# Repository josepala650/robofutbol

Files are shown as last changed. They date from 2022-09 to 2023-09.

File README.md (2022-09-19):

# robofutbol
Robot para competencia robotfutbol
En este repositorio se encuentra el manual para ensamblar el mismo asi como las piezas que se necesitan .
Tambien puede verse el siguiente video:
https://www.youtube.com/watch?v=j2guSepUVq8&t=1s 
Captura de pantalla de 2022-04-13 15-39-39

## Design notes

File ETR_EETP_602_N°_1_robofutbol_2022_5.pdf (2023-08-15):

# Manual de robotfutbol con arduino

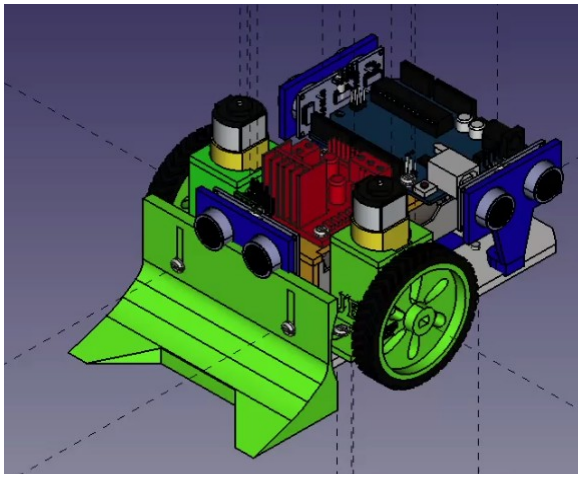
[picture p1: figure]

# Autor: Profesor Palacios José Emanuel

# Año: 2022 Institución: Escuela de Educación Técnico Profesional Nº 602 "Gral San Martín" www.eetp602.edu.ar

# Manual de Robot_Futbol con Arduino

# Contenido

Profesor Técnico Palacios José Emanuel | Página 2

# Manual de Robot_Futbol con Arduino

Introducción: Robotfutbol.

En este manual desarrollaremos un robotfutbol funcional básico, que se espera sufra modificaciones por quien lee este manual. Los robotsfutbol son robots que tienen como objetivo introducir una pelota en el arco del reival, para ellos son operados por radiocontrol (bluethooth, rf,etc). En el siguiente enlace se ve una descripción del robotfutbol.

# DIY Robot Futbolista - Campeonato Local de Robots [ARDUINO]

# https://youtu.be/g5vMoPJQiVI

Materiales.

- 1x Arduino uno
- 1x Chasis que cumpla con las normas de la categoría (se proporcionaran planos de ejemplo).
- 2x motoreductor arduino
- Rueda para motoreductor arduino ( se proporciona plano para su diseño 3d).
- shiel doble puente h l298n.
- Porta baterías 18650 x2.
- Baterías recargables tipo 18650 3.7v 5000 Mah
- Plug de alimentación DC 2.1mm
- 30 tornillos cabeza tanque de 1/8 de 10mm con tuerca.
- 2 tornillos cabeza tanque de 1/8 de 30mm con tuerca (para la pala).
- 2 tornillo m2 X 15mm(diametro2mm) para sujetar ruedas.
- 20 conector dupont macho hembra 10cm
- 20 conector dupont macho macho10cm
- Cable 1mm rojo y negro, 50cm.
- Tecla on/0ff.
- Modulo bluetooth HC06
- 4 Diodo rectificador 1n4007
- Cinta aisladora o termocontraible (de 3 a 1mm).
- Estaño
- Piezas del diseño de chasis (archivos stl para descargar https://youtu.be/j2guSepUVq8 )

# Manual de Robot_Futbol con Arduino

# Interruptor on/off y alimentación

Es conveniente agregar un interruptor para la alimentación del circuito, en serie a un diodo rectificador 1N4007 (para proteger el circuito en caso de conectar las baterías con la polaridad incorrecta), de acuerdo al consumo es la cantidad de diodos 1N4007 que conectaremos ya que cada diodo soporta 1A, en este caso conectaremos 2 diodos en paralelo para que soporten 2A, de necesitar que soporte mas amperaje incrementar la cantidad de diodos o colocar uno que soporte dicho amperaje.

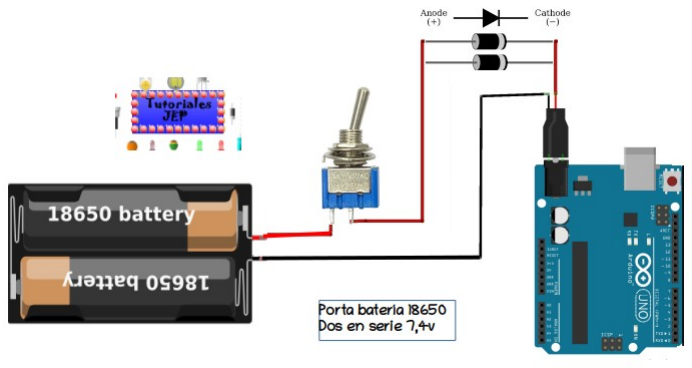
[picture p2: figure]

# Manual de Robot_Futbol con Arduino

# Control por Bluetooth

Este tutorial tiene el objetivo principal de dar los conocimientos necesarios para poder añadir a nuestro

Arduino la función de poder comunicarse sin cables con otros dispositivos mediante módulos Bluetooth y

poder empezar a incorporarlos en nuestro robot.

Es necesario saber que existen diferentes modelos de módulos Bluetooth entre los más populares se encuentran HC-06 y el HC05, y entre ellos diferentes modelos.

Un módulo Bluetooth HC-06 se comporta como esclavo, esperando peticiones de conexión, Si algún dispositivo se conecta, el HC-06 transmite a este todos los datos que recibe del Arduino y viceversa.

## Entonces, ¿cuáles son sus diferencias entre el modulo Bluetooth HC-06

# y el HC-05?

El módulo HC-06 es prácticamente idéntico a simple vista con los demás módulos que existen en el mercado.

Una simple diferencia es que el módulo HC-06 funciona como Slave y el HC-05 como Master y Slave (lo que podría confundir a algunos).

Físicamente se diferencian por el número de pines. En el HC-06 tiene un conector de 4 pines mientras que el HC-05 trae uno de 6 pines.

HC-06 | HC-05

Para este tutorial trabajaremos un módulo HC06 pero también es válido para un módulo HC-05 en modo Esclavo, que es su configuración que viene por defecto.

# EL HC-06 tiene 4 pines:

- Vcc, Voltaje positivo de alimentación, aquí hay tener cuidado porque hay módulos que solo soportan voltajes de 3.3V, pero en su mayoría ya vienen acondicionados para q trabajen en el rango de 3.3V a 6V

# pero es bueno revisar los dato técnicos de nuestro modulo antes de hacer las conexiones

- GND, Voltaje negativo de alimentación, se tienen que conectar al GND del Arduino o al GND de la placa que se esté usando.
- TX, Pin de Transmisión de datos, por este pin el HC-06 transmite los datos que le llegan desde la PC o

# Móvil mediante bluetooth, este pin debe ir conectado al pin RX del Arduino

# Manual de Robot_Futbol con Arduino

-RX, pin de Recepción, a través de este pin el HC-06 recibirá los datos del Arduino los cuales se

# transmitirán por Bluetooth, este pin va conectado al Pin TX del Arduino

Explicado esto, para comenzar a hacer pruebas y comprobar que nuestro HC-06 nos funciona correctamente, usando cables Dupont macho-hembra procedemos a realizar las siguientes conexiones entre nuestro modulo Bluetooth y nuestro Arduino UNO R3(se pueden realizar las mismas conexiones con el Arduino Mega, Arduino Nano, etc. e iría perfectamente).

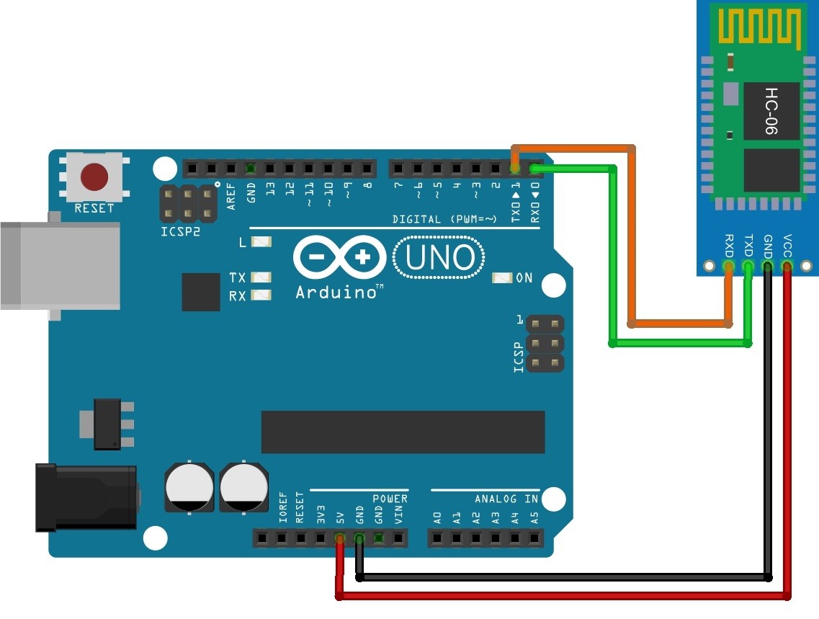
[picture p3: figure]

Para cargar el programa al Arduino, desconectaremos los pines RX0 y TX0 del Arduino, pues internamente el Arduino trabaja con los mismos pines para cargar el programa y si están conectados al módulo Bluetooth, no nos dejara cargar (para evitar este inconveniente se puede usar el software serial y usar otros pines).

# Manual de Robot_Futbol con Arduino

Ahora en el IDE de Arduino copiamos el siguiente código y luego lo cargamos a nuestro Arduino.

/**********************************************************************/
/* Autor: Palacios José Emanuel docente de la EETPN°602 | */
/* Programa:Prueba bluetooth | */
/* Año:2022 | */
/**********************************************************************/

# void setup()

{
Serial.begin(9600);

pinMode(12, OUTPUT); // configuro el pin 13 como salida
}

# void loop()

{

# if (Serial.available())

{
char dato=Serial.read();

# if (dato=='a')

{

# digitalWrite(13,HIGH); //envió 5V al pin13 donde esta conectado el led

}

# if (dato=='b')

{

# digitalWrite(13,LOW); //envió 0V al pin13 donde esta conectado el led

}
}
}
Después | de | terminar | de | cargar, | nuevamente | volvemos | a | conectar | los | pines | RX | y TX.

El programa que hemos cargado al Arduino básicamente de acuerdo al dato que reciba del Bluetooth ( a o b) prendera o apagara el led conectado al pin13.

# En el siguiente videotutorial se muestra como hacer la app para control por bluetooth

Crear Aplicación para Carro a Control Remoto (Tutorial):https://youtu.be/MiWLzbpfqr0

En el siguiente enlace encontrara una app de manejo por bluetooth que permite su configuración según se

necesite.

https://play.google.com/store/apps/details?id=nextprototypes.BTSerialController&hl=es_AR&gl=US

# Manual de Robot_Futbol con Arduino

# Control de Motores

Nos queda por probar el movimiento de los motores, estos funcionan con un voltaje de corriente directa, para controlar el giro y la velocidad se usará un driver de motores.

Primero soldaremos los cables a los motores.

Se deben soldar los cables de manera perpendicular al motor de modo que la longitud del motor sea lo más corta posible (ahora que se ha incluido el cable).

Una vez soldados los motores debemos conectarlos al driver.
Shiel doble puente h l298n.

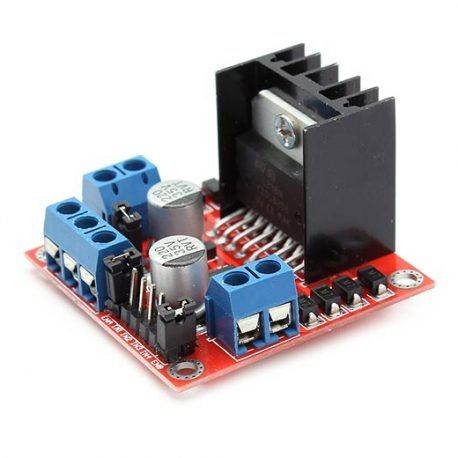
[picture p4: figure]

# Manual de Robot_Futbol con Arduino

Este módulo es el complemento ideal para proyectos de robótica y Router CNC. Permite controlar hasta 2

motores de corriente continua o un motor paso a paso bipolar. También permite controlar un motor paso a

paso unipolar configurado como bipolar de forma muy sencilla y eficaz.

### Características

- Voltaje de alimentación, mínimo de 5 V. Posee dos entradas, una de 5V para controlar la parte lógica y otra para alimentar las salidas al motor, que pueden ser de 5V o más.
- La tarjeta tiene la opción de habilitar un regulador LM7805 integrado en ella para alimentar la parte lógica con lo que se puede alimentar la tarjeta con 12V por ejemplo.
- Corriente máxima 2 Amperios.

# - Posee 6 entradas de control (ver tabla de control)

- Admite entradas de señal PWM para el control de velocidad.
- Dimensiones: 43 mm x 23,9 mm x 43 mm.
- Salidas: para 2 motores de DC o para un motor bipolar paso a paso.

# Manual de Robot_Futbol con Arduino

# Funcionamiento del puente H

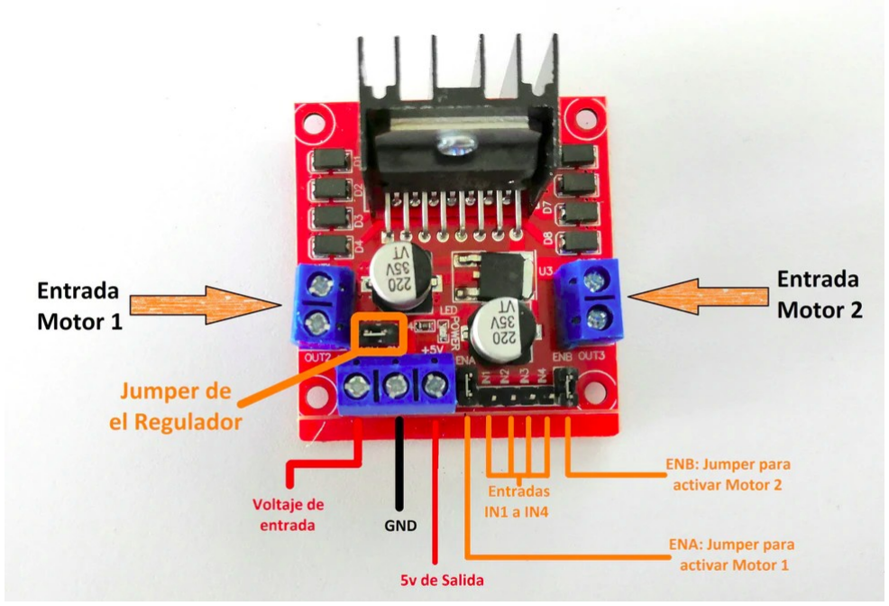
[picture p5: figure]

El voltaje de entrada puede ser desde 3v hasta 35v, aun lado de la entrada de voltaje contamos con el

GND

# La tercera es la salida lógica de 5v la cual se utiliza de la siguiente manera:

- Si el jumper se encuentra puesto se activará el regulador de tensión y tendremos una salida de 5V, que podremos usar para darle potencia a otro componente.
- Si quitamos el jumper desactivaremos el regulador, necesitaríamos alimentar el módulo, Tendríamos que ingresar 5v por la salida lógica para que el modulo funcione.
- ¡PRECAUCION! Si ingresamos 5v por la parte lógica con el jumper puesto podríamos causar daño a la tarjeta.
- El regulador solo nos funciona si ingresamos un voltaje desde 5v hasta 12v, Si queremos ingresar un voltaje mayor tendríamos que quitar el jumper y alimentar el modulo con 5v con una fuente externa.

Las salidas de los motores 1 y 2 nos dan energía para mover los motores. Hay que tomar en cuenta las polaridades de los motores para que queden girando hacia adelante. En caso de que un motor este girando al lado contrario solo es necesario invertir los cables.

Los dos pines IN1 e IN2 sirven para controlar el sentido de giro en el motor 1, y los dos pines IN3 e IN4 el sentido de giro del motor 2.

# Manual de Robot_Futbol con Arduino

# Funcionan de la siguiente manera:

Si IN1 le llegan 5v y al IN2 0v, el motor 1 gira en un sentido, y si IN1 le llegan 0v y a IN2 5v lo hace en el sentido contrario.

Sería lo mismo con los pines IN3 e IN4 para el motor 2.

Para controlar la velocidad a la que van a girar los motores tenemos que retirar los jumpers en ENA y ENB. Los tenemos que conectar a dos salidas PWM de nuestro Arduino con el cual enviaremos una señal con un valor entre 0 y 255 para que controle la velocidad de giro. Si no quitamos los jumpers, los motores estarán

# girando a la misma velocidad siempre( que es el caso que se explica en este tutorial)

La siguiente imagen muestra las conexiones a realizar, para los pines ENA y ENB se dejan con los jumpers pero si quieren controlar la velocidad podemos utilizar cualquier conexión PWM en el arduino quitando los jumpers.

Conexiones

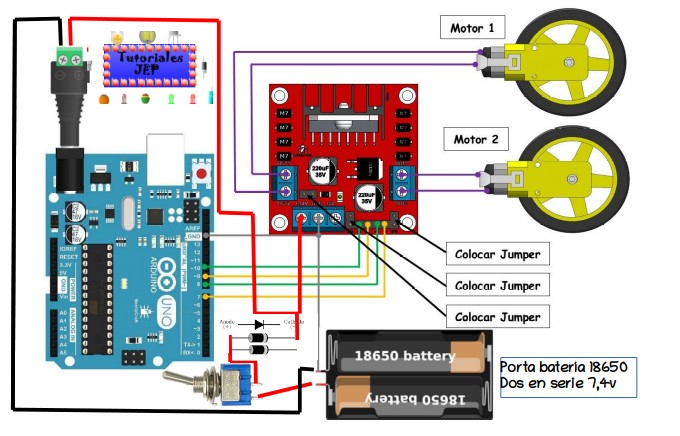
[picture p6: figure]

# Manual de Robot_Futbol con Arduino

# Programación para controlar el puente h

A continuación tenemos un código de ejemplo para controlar los motores:

/**********************************************************************/
/* Autor: Palacios José Emanuel docente de la EETPN°602 | */
/* Programa:Prueba motores | */
/* Año:2022 | */
/**********************************************************************/

// Conexiones puente h
//motor 1
int IN1=10; // enmascaro al pin 10 con el nombre de IN1 int IN2=9; // enmascaro al pin 9 con el nombre de IN2

//motor 2
int IN3=8; // enmascaro al pin 8 con el nombre de IN3
int IN4=7; // enmascaro al pin 7 con el nombre de IN4

// **************************** Inicialización *************************************
void setup() {
pinMode(IN1, OUTPUT); // configuro el pin donde conecte IN1 como salida pinMode(IN2, OUTPUT); // configuro el pin donde conecte IN2 como salida pinMode(IN3, OUTPUT); // configuro el pin donde conecte IN3 como salida pinMode(IN4, OUTPUT); // configuro el pin donde conecte IN4 como salida
}

//***************************** programa principal *******************************
void loop() {

//giro motor 1 sentido horario
digitalWrite(IN1,HIGH); //envió 5V al pin donde conecte IN1 digitalWrite(IN2,LOW); //envió 0V al pin donde conecte IN2 delay(1000); // Temporiza un segundo (1s = 1000ms)

//giro motor 1 sentido anti horario
digitalWrite(IN1,LOW); //envió 0V al pin donde conecte IN1 digitalWrite(IN2,HIGH); //envió 5V al pin donde conecte IN2 delay(1000); // Temporiza un segundo (1s = 1000ms)

//motor 1 DETENIDO
digitalWrite(IN1,LOW); //envió 0V al pin donde conecte IN1 digitalWrite(IN2,LOW); //envió 0V al pin donde conecte IN2 delay(1000); // Temporiza un segundo (1s = 1000ms)

//giro motor 2 sentido horario
digitalWrite(IN3,HIGH); //envió 5V al pin donde conecte IN3 digitalWrite(IN4,LOW); //envió 0V al pin donde conecte IN4 delay(1000); // Temporiza un segundo (1s = 1000ms)

//giro motor 2 sentido antihorario
digitalWrite(IN3,LOW); //envió 0V al pin donde conecte IN3 digitalWrite(IN4,HIGH); //envió 5V al pin donde conecte IN4 delay(1000); // Temporiza un segundo (1s = 1000ms)

//motor 2 DETENIDO
digitalWrite(IN3,LOW); //envió 0V al pin donde conecte IN3

# Manual de Robot_Futbol con Arduino

digitalWrite(IN4,LOW); //envío 0V al pin donde conecte IN4 delay(1000); // Temporiza un segundo (1s = 1000ms)
}

# Manual de Robot_Futbol con Arduino

## Lógica de movimiento

La estructura que hemos elegido para nuestro robot nos permitirá realizar movimientos hacia Adelante, hacia Atrás, giros a la Derecha, ala Izquierda y sobre sí mismo.
Movimiento hacia delante: Se hacen girar los dos motores en la misma dirección (sentido horario), esto provoca un movimiento recto hacia delante de la estructura.

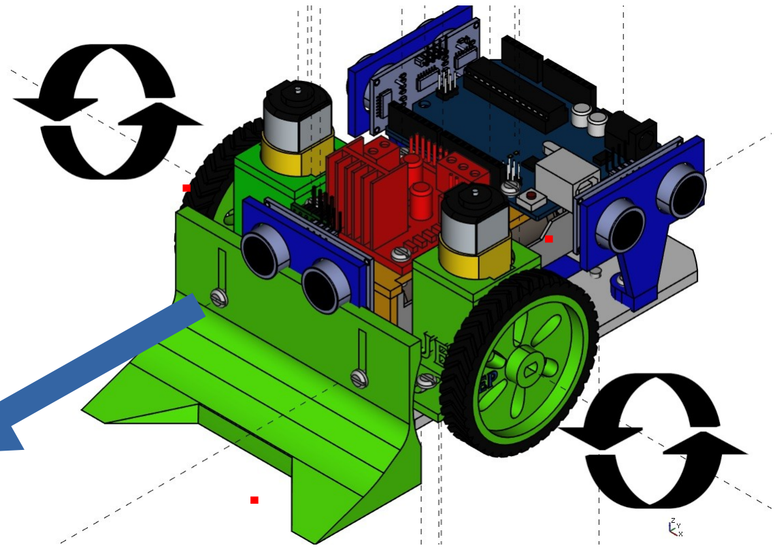
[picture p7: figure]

Movimiento hacia atrás: Se hacen girar los dos motores en la misma dirección (antihorario), esto provoca un movimiento recto hacia atrás de la estructura.

# Manual de Robot_Futbol con Arduino

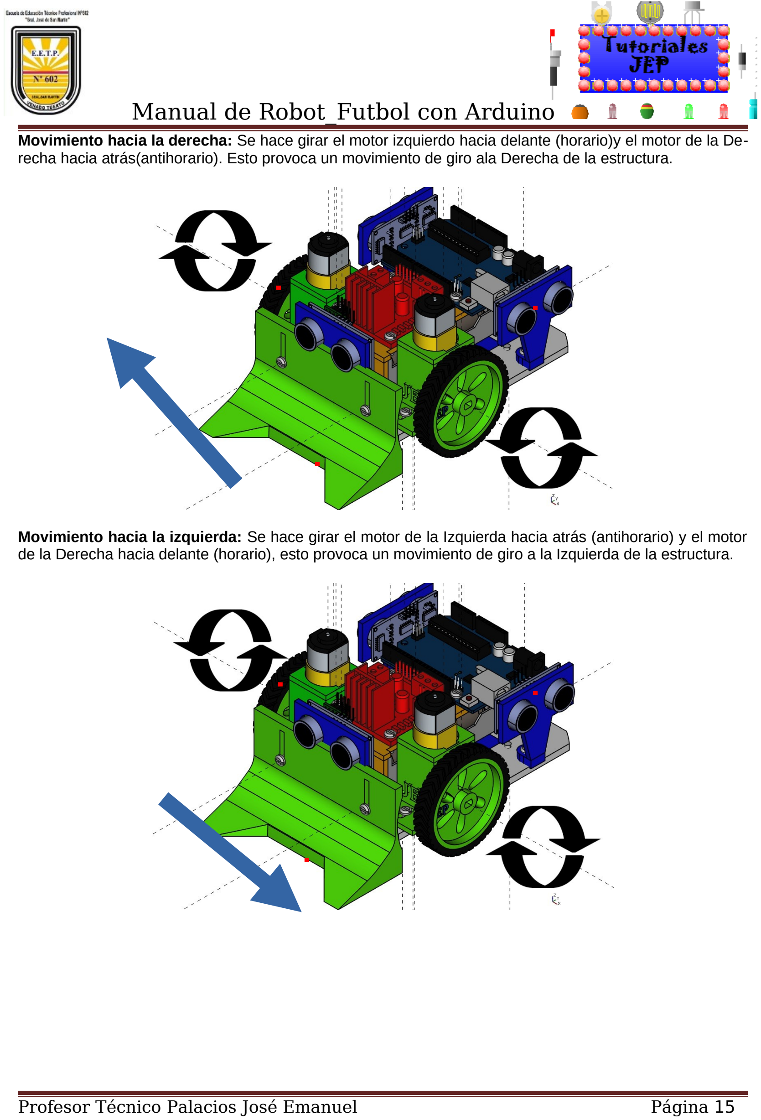
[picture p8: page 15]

Movimiento hacia la derecha: Se hace girar el motor izquierdo hacia delante (horario)y el motor de la Derecha hacia atrás(antihorario). Esto provoca un movimiento de giro ala Derecha de la estructura.

Movimiento hacia la izquierda: Se hace girar el motor de la Izquierda hacia atrás (antihorario) y el motor de la Derecha hacia delante (horario), esto provoca un movimiento de giro a la Izquierda de la estructura.

# Manual de Robot_Futbol con Arduino

# El código de Arduino quedaría de la siguiente manera:

/**********************************************************************/
/* Autor: Palacios José Emanuel docente de la EETPN°602 | */
/* Programa:movimiento de robot | */
/* Año:2022 | */
/**********************************************************************/
// Conexiones puente h
//motor 1_izquierdo
int IN1=10; // enmascaro al pin 10 con el nombre de IN1
int IN2=9; // enmascaro al pin 9 con el nombre de IN2

//motor 2_derecho
int IN3=8; // enmascaro al pin 8 con el nombre de IN3 int IN4=7; // enmascaro al pin 7 con el nombre de IN4

void setup()
{

pinMode(IN1, OUTPUT); // configuro el pin donde conecte IN1 como salida pinMode(IN2, OUTPUT); // configuro el pin donde conecte IN2 como salida pinMode(IN3, OUTPUT); // configuro el pin donde conecte IN3 como salida pinMode(IN4, OUTPUT); // configuro el pin donde conecte IN4 como salida
}

void loop()
{
// voy hacia adelante por un segundo

//giro motor 1 sentido anti horario
digitalWrite(IN1,LOW); //envió 0V al pin donde conecte IN1 digitalWrite(IN2,HIGH); //envió 5V al pin donde conecte IN2 //giro motor 2 sentido horario
digitalWrite(IN3,HIGH); //envió 5V al pin donde conecte IN3 digitalWrite(IN4,LOW); //envió 0V al pin donde conecte IN4 delay(1000);// demora de un segundo

//voy hacia atrás por un segundo

//giro motor 1 sentido horario
digitalWrite(IN1,HIGH); //envió 5V al pin donde conecte IN1 digitalWrite(IN2,LOW); //envió 0V al pin donde conecte IN2 //giro motor 2 sentido antihorario
digitalWrite(IN3,LOW); //envió 0V al pin donde conecte IN3 digitalWrite(IN4,HIGH); //envió 5V al pin donde conecte IN4 delay(1000);// demora de un segundo

//voy a la derecha con ambas ruedas por un segundo

//giro motor 1 sentido anti horario
digitalWrite(IN1,LOW); //envió 0V al pin donde conecte IN1 digitalWrite(IN2,HIGH); //envió 5V al pin donde conecte IN2 //giro motor 2 sentido antihorario
digitalWrite(IN3,LOW); //envió 0V al pin donde conecte IN3 digitalWrite(IN4,HIGH); //envió 5V al pin donde conecte IN4 delay(1000);// demora de un segundo

# Manual de Robot_Futbol con Arduino

// voy a la izquierda con ambas ruedas por un segundo

//giro motor 1 sentido horario
digitalWrite(IN1,HIGH); //envió 5V al pin donde conecte IN1 digitalWrite(IN2,LOW); //envió 0V al pin donde conecte IN2 //giro motor 2 sentido horario
digitalWrite(IN3,HIGH); //envió 5V al pin donde conecte IN3 digitalWrite(IN4,LOW); //envió 0V al pin donde conecte IN4 delay(1000);// demora de un segundo

// me detengo por un segundo

//motor 1 DETENIDO
digitalWrite(IN1,LOW); //envió 0V al pin donde conecte IN1 digitalWrite(IN2,LOW); //envió 0V al pin donde conecte IN2 //motor 2 DETENIDO
digitalWrite(IN3,LOW); //envió 0V al pin donde conecte IN3 digitalWrite(IN4,LOW); //envío 0V al pin donde conecte IN4 delay(1000);// demora de un segundo

// voy a la derecha con una rueda por un segundo

//giro motor 1 sentido anti horario
digitalWrite(IN1,LOW); //envió 0V al pin donde conecte IN1 digitalWrite(IN2,HIGH); //envió 5V al pin donde conecte IN2 delay(100);// demora de 10milisegundos
//motor 1 DETENIDO
digitalWrite(IN1,LOW); //envió 0V al pin donde conecte IN1 digitalWrite(IN2,LOW); //envió 0V al pin donde conecte IN2 delay(1000);// demora de un segundo

//voy a la izquierda con una rueda por un segundo

//giro motor 2 sentido horario
digitalWrite(IN3,HIGH); //envió 5V al pin donde conecte IN3 digitalWrite(IN4,LOW); //envió 0V al pin donde conecte IN4 delay(100);//demora de 10milisegundos
//motor 2 DETENIDO
digitalWrite(IN3,LOW); //envió 0V al pin donde conecte IN3 digitalWrite(IN4,LOW); //envío 0V al pin donde conecte IN4 delay(1000);// demora de un segundo

}

Con este programa comprobamos los movimientos del robot.

# Manual de Robot_Futbol con Arduino

Montaje de los componentes.

Cuando ya se han probado todos los componentes por separado lo siguiente es montar todo el circuito electrónico, sensores, motores y control en el chasis. Recomendamos el tornillos.

1) Partiremos por la base impresa en 3d

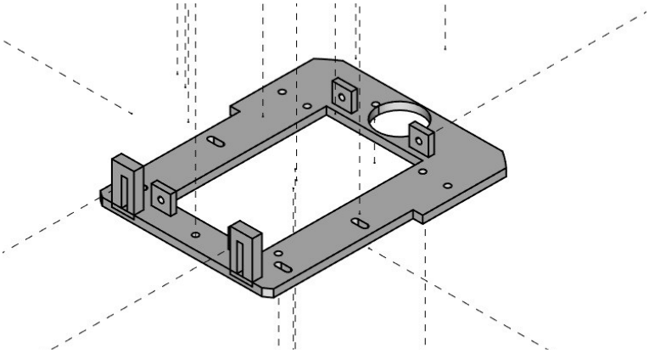
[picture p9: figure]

# Manual de Robot_Futbol con Arduino

# Rueda loca

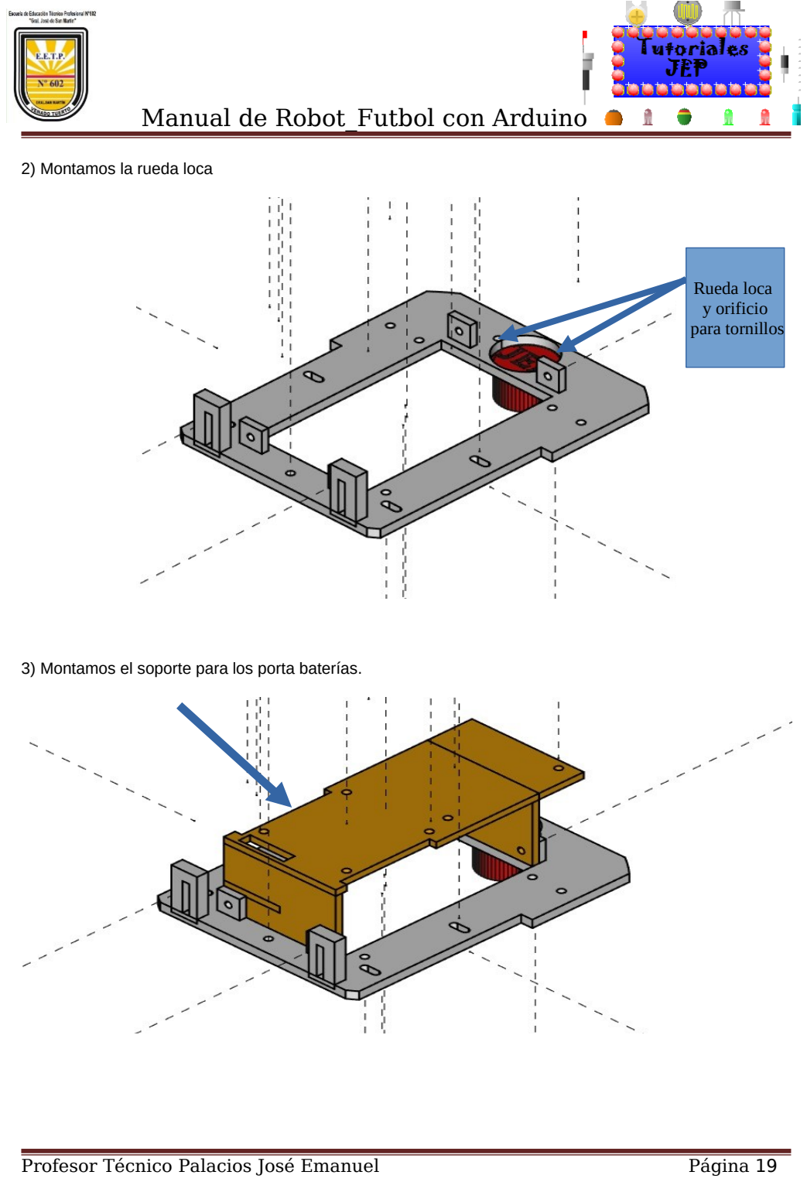
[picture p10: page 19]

2) Montamos la rueda loca
3) Montamos el soporte para los porta baterías.

# y orificio para tornillos

# Manual de Robot_Futbol con Arduino

4) Aquí el detalle de los tornillos de sujeción.

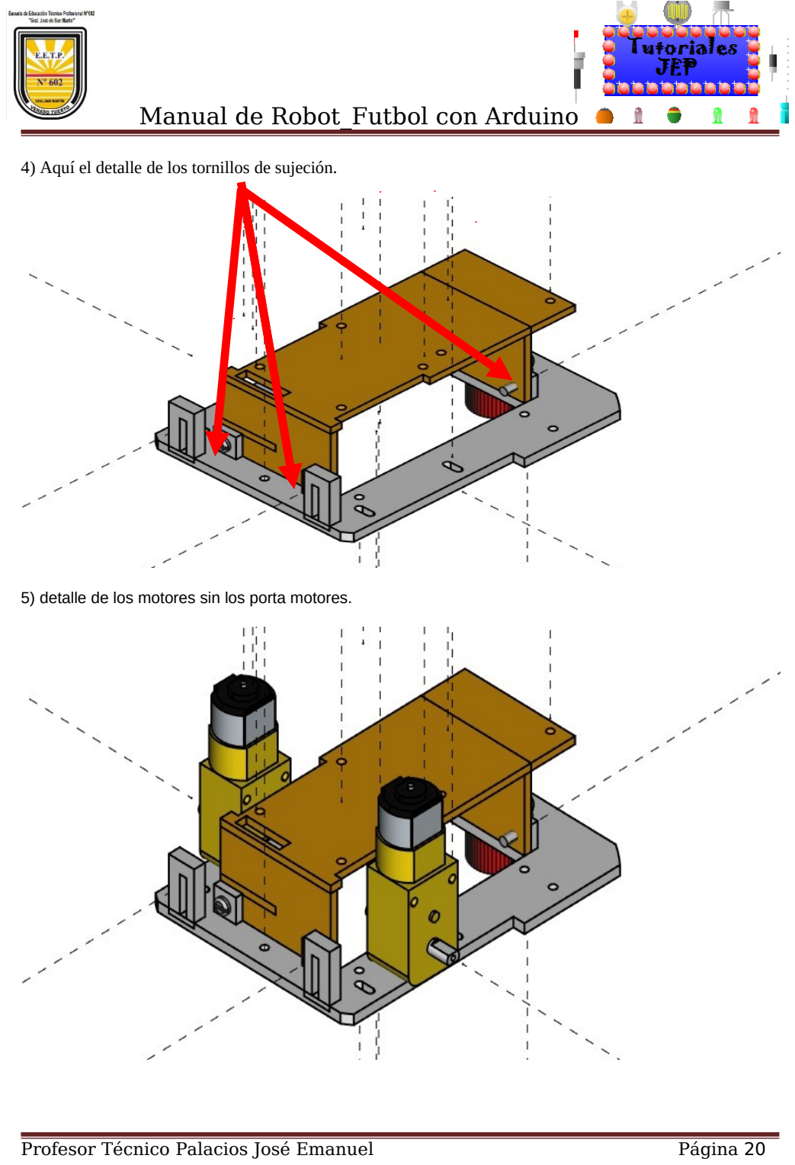
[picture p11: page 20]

5) detalle de los motores sin los porta motores.

# Manual de Robot_Futbol con Arduino

# motor

6) Detalle de los motores con los porta motores.
7) Colocamos las rudas (llanta y cubierta).

# portamotor

# tornillos

# Manual de Robot_Futbol con Arduino

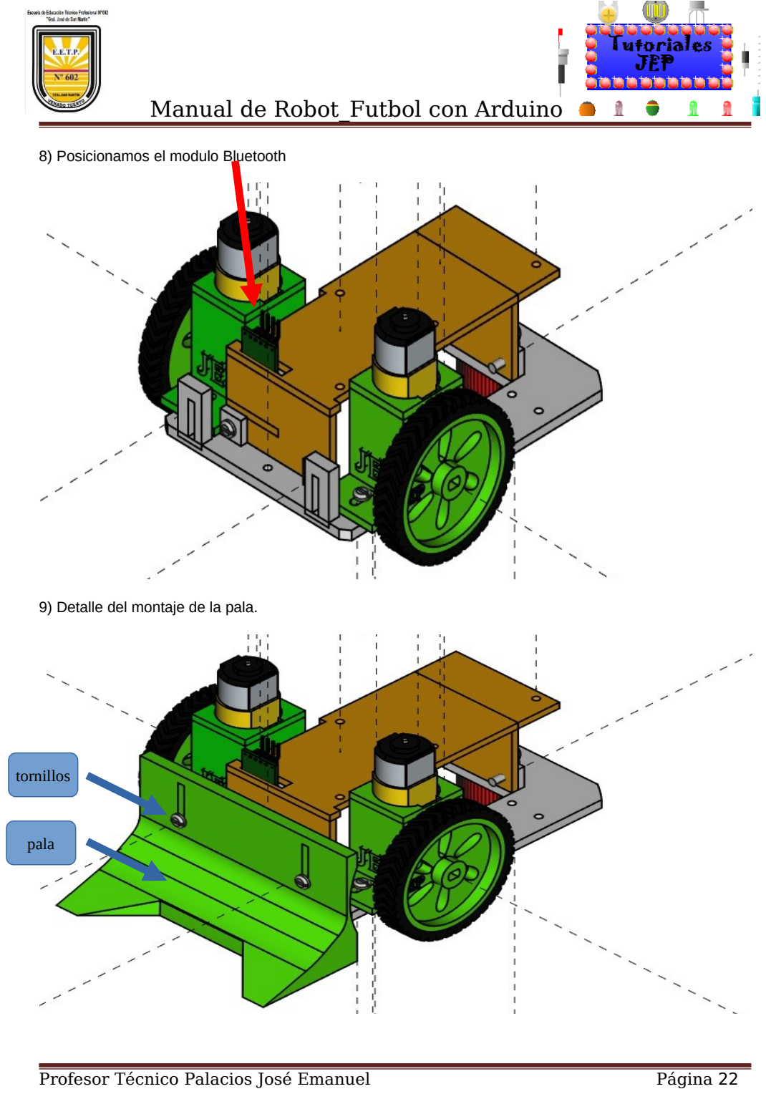
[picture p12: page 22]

8) Posicionamos el modulo Bluetooth
9) Detalle del montaje de la pala.

# tornillos

# pala

# Manual de Robot_Futbol con Arduino

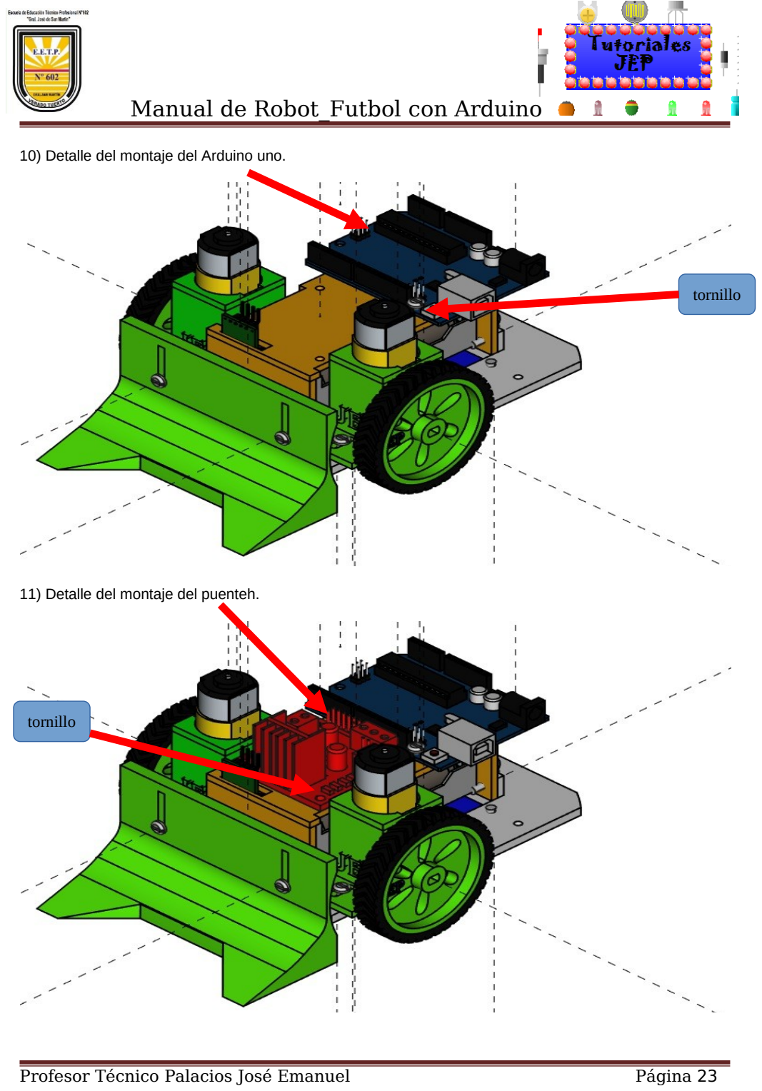
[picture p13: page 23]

10) Detalle del montaje del Arduino uno.
11) Detalle del montaje del puenteh.

# tornillo

# tornillo

# Manual de Robot_Futbol con Arduino

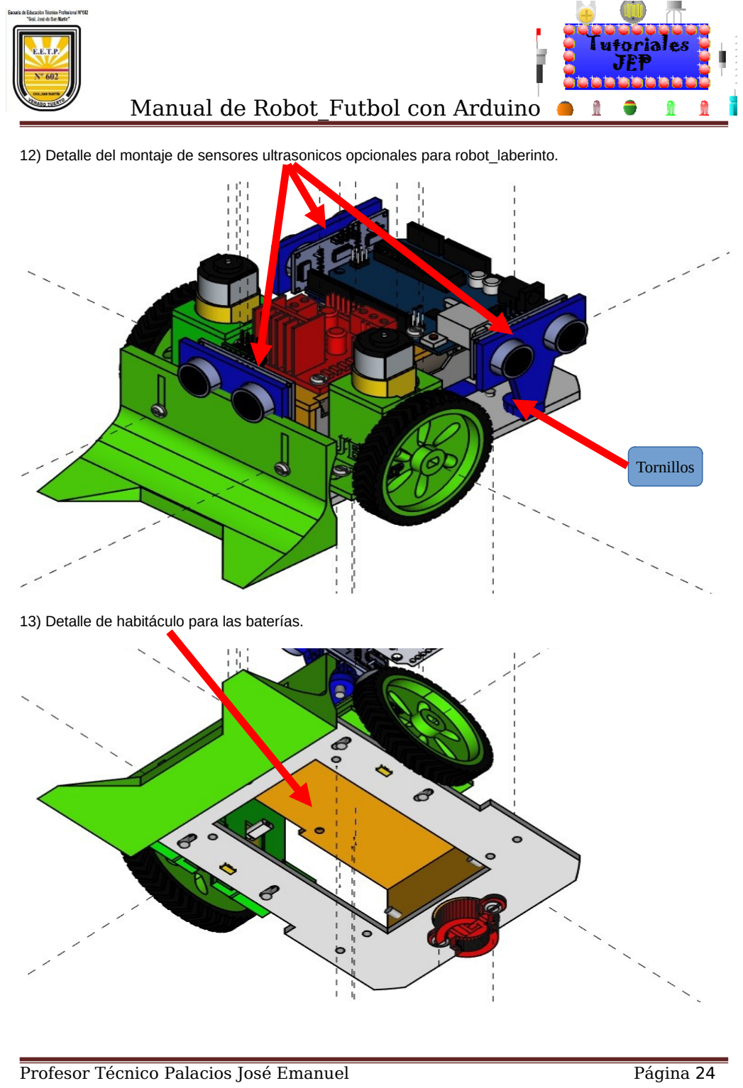
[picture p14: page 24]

12) Detalle del montaje de sensores ultrasonicos opcionales para robot_laberinto.
13) Detalle de habitáculo para las baterías.

# Tornillos

# Manual de Robot_Futbol con Arduino

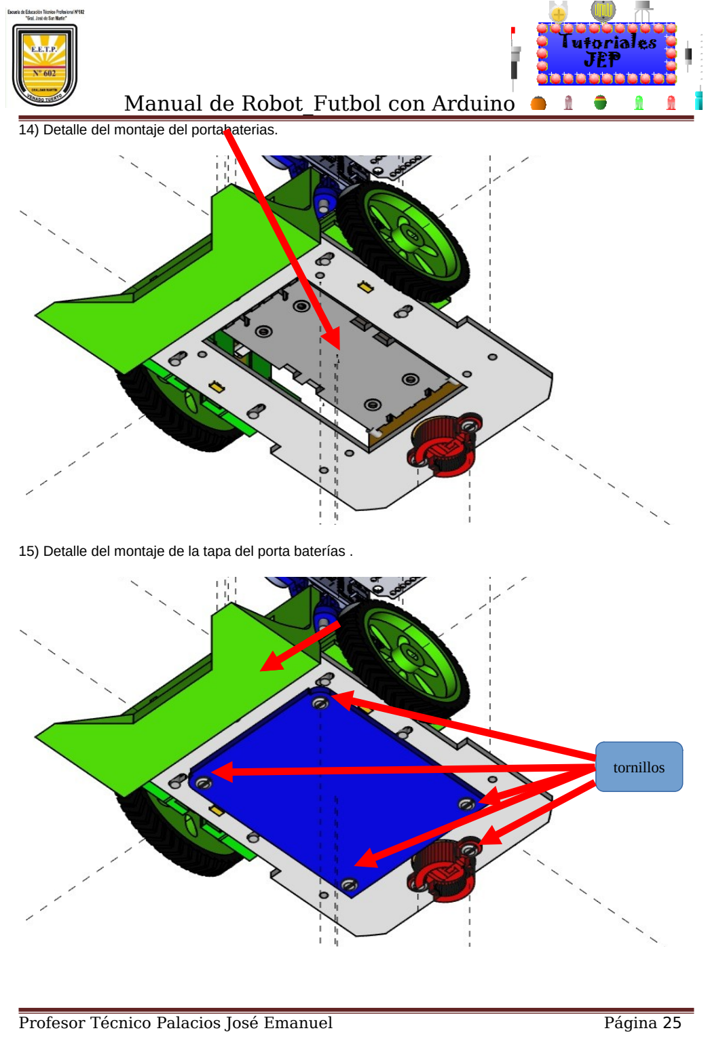
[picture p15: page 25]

14) Detalle del montaje del portabaterias.
15) Detalle del montaje de la tapa del porta baterías .

# tornillos

# Manual de Robot_Futbol con Arduino

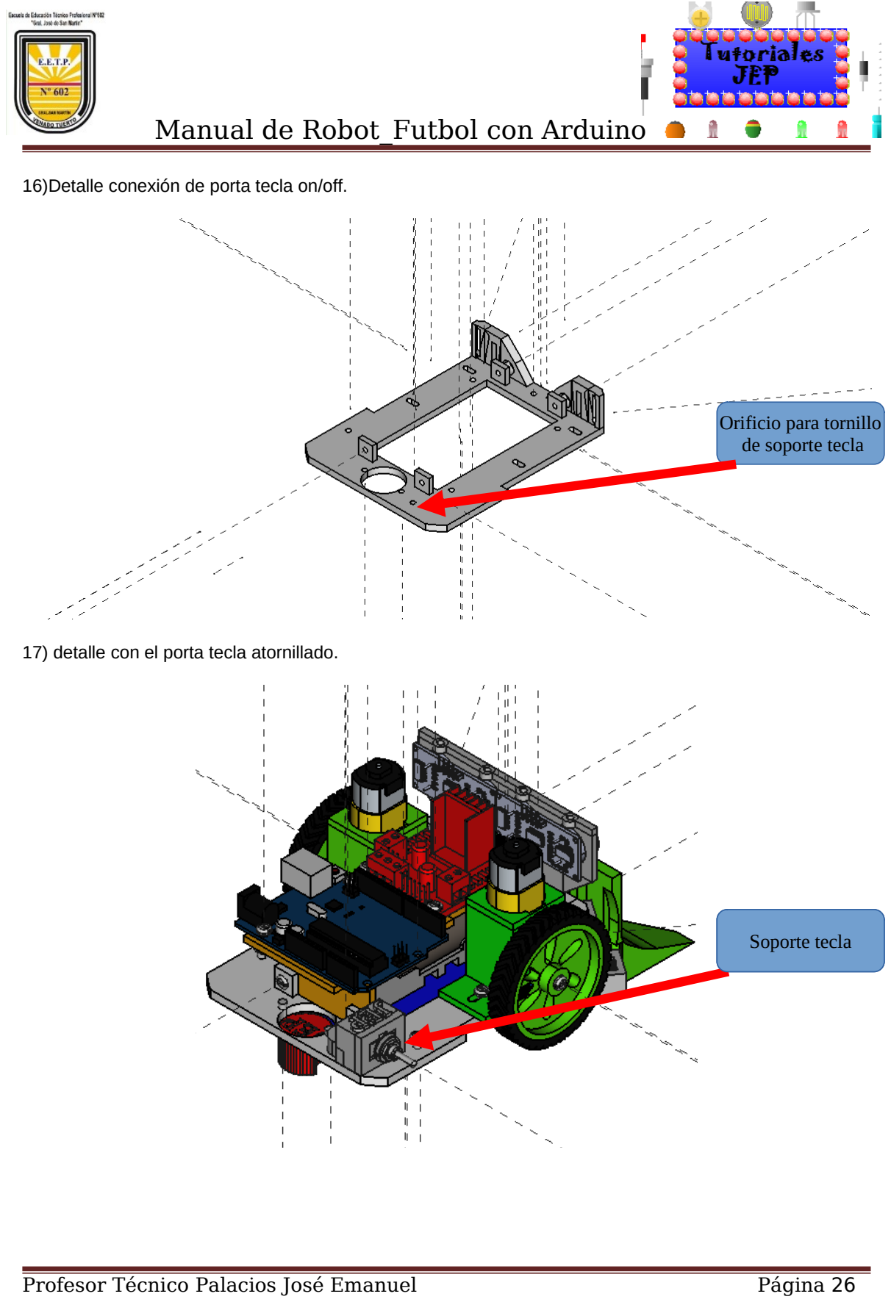
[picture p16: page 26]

16)Detalle conexión de porta tecla on/off.

17) detalle con el porta tecla atornillado.

# Orificio para tornillo de soporte tecla

# Soporte tecla

# Manual de Robot_Futbol con Arduino

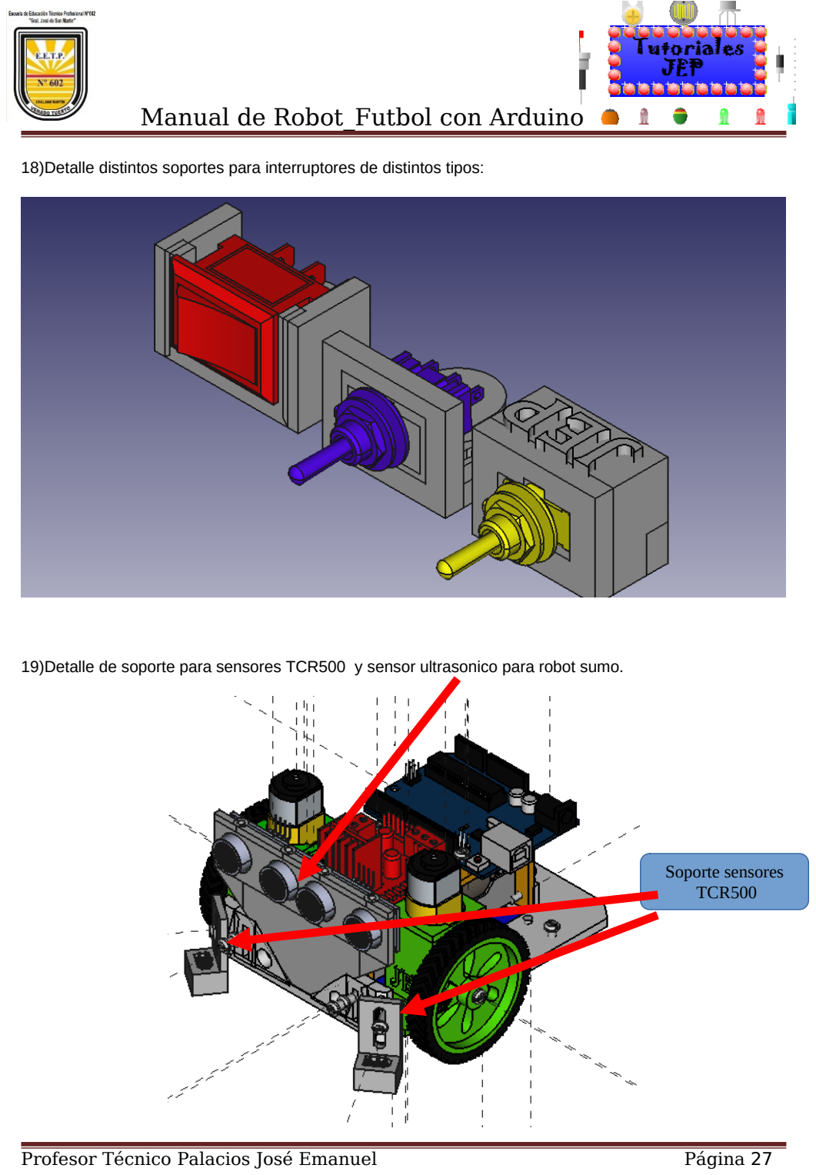
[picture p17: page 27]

18)Detalle distintos soportes para interruptores de distintos tipos:

19)Detalle de soporte para sensores TCR500 y sensor ultrasonico para robot sumo.

# Soporte sensores TCR500

# Manual de Robot_Futbol con Arduino

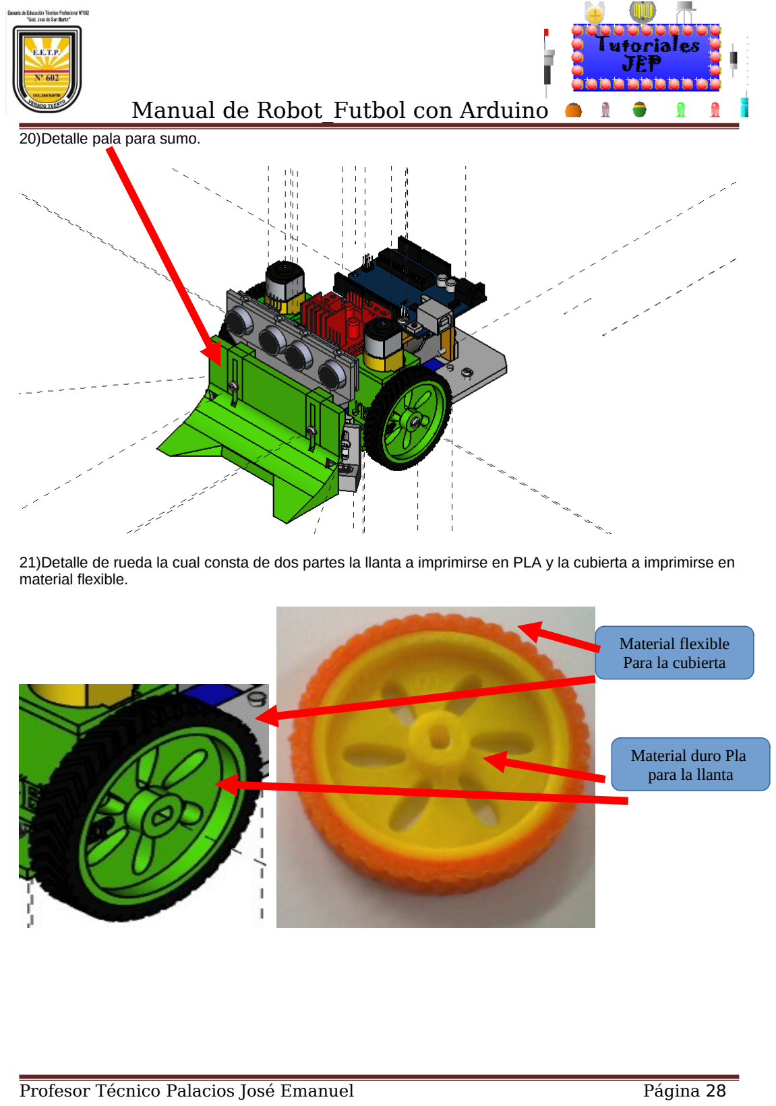
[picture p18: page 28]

20)Detalle pala para sumo.

21)Detalle de rueda la cual consta de dos partes la llanta a imprimirse en PLA y la cubierta a imprimirse en material flexible.

# Material flexible Para la cubierta

# Material duro Pla para la llanta

# Manual de Robot_Futbol con Arduino

22) Detalle soporte para modulo Bluetooth y modulo RF receptor.

# Manual de Robot_Futbol con Arduino

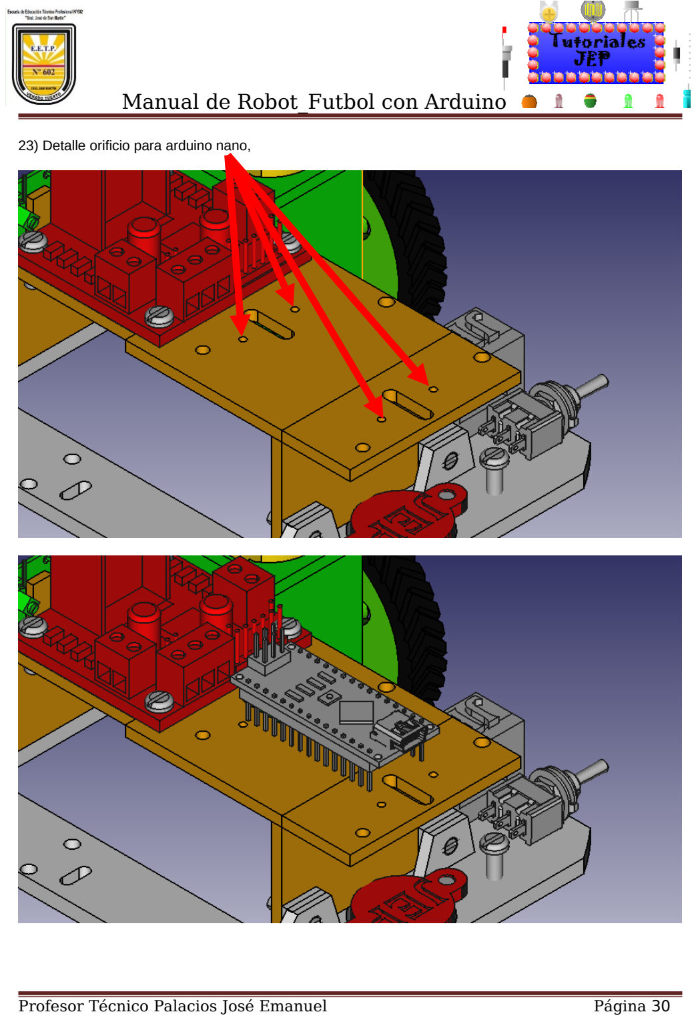
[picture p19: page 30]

23) Detalle orificio para arduino nano,

# Manual de Robot_Futbol con Arduino

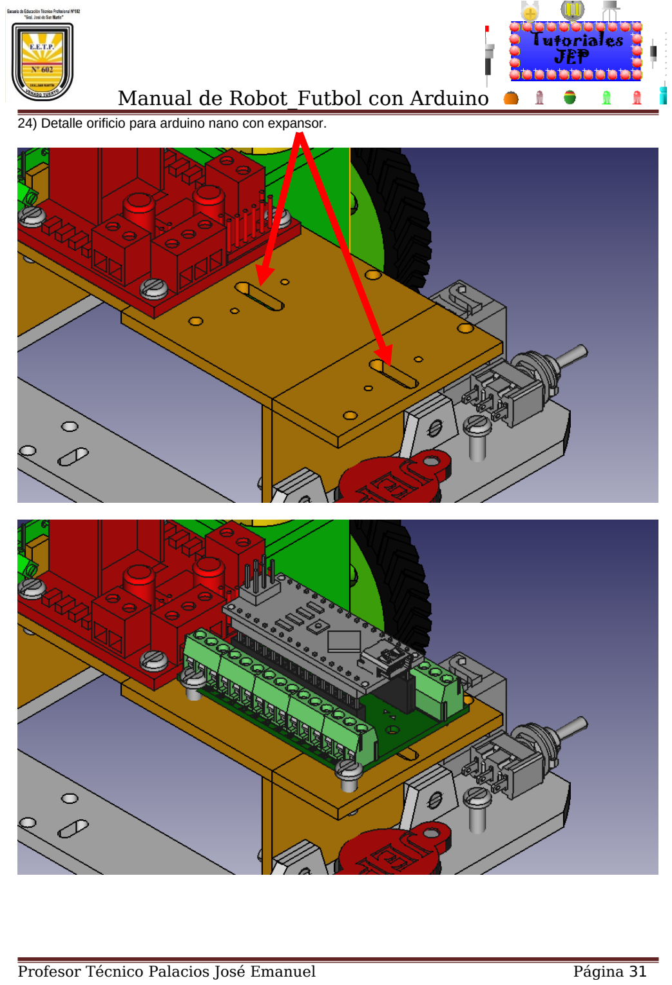
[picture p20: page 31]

24) Detalle orificio para arduino nano con expansor.

# Manual de Robot_Futbol con Arduino

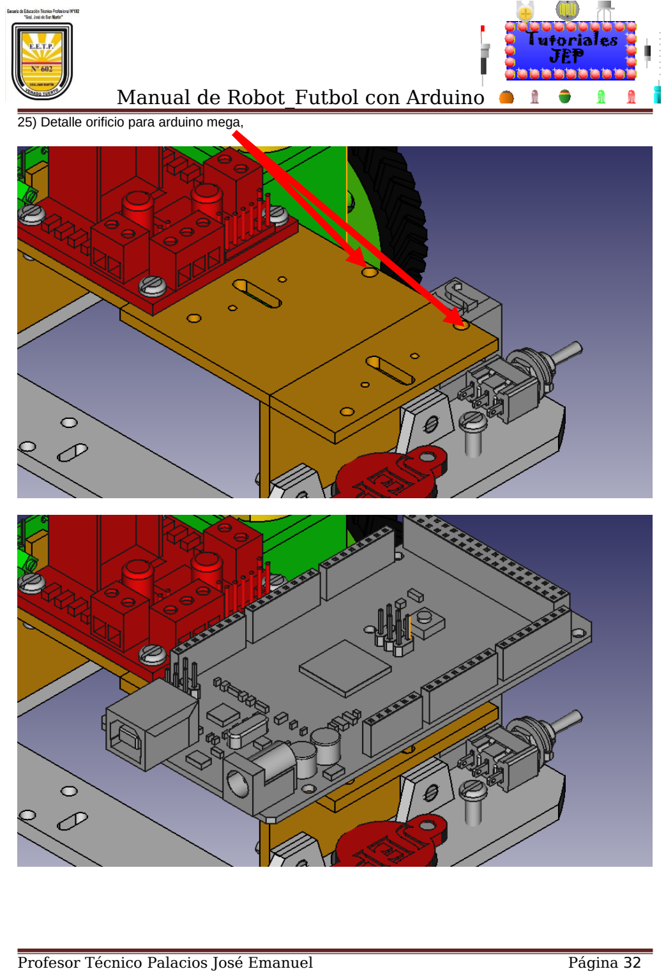
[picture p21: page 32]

25) Detalle orificio para arduino mega,

# Manual de Robot_Futbol con Arduino

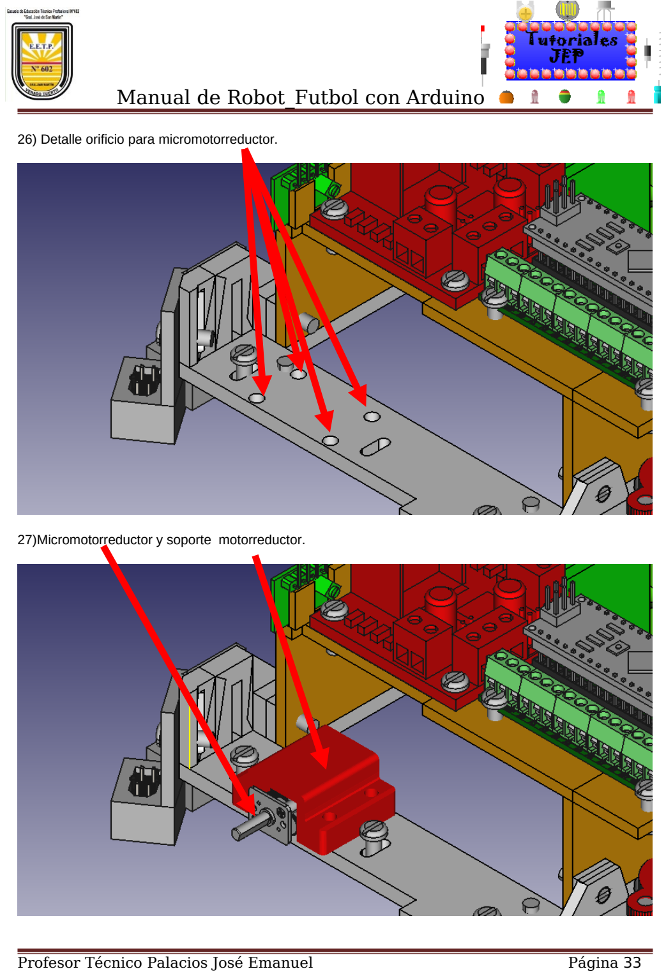
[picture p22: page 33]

26) Detalle orificio para micromotorreductor.

27)Micromotorreductor y soporte motorreductor.

# Manual de Robot_Futbol con Arduino

# Programación de la aplicación final

Para unir todas las funciones se hace un programa que revisa los datos recibidos por el bluetooth para

tomar una decisión de hacia dónde debe moverse.

# El diagrama de flujo sería el siguiente:

# Manual de Robot_Futbol con Arduino

# Manual de Robot_Futbol con Arduino

# El código de Arduino quedaría de la siguiente manera:

/**********************************************************************/
/* Autor: Palacios José Emanuel docente de la EETPN°602 | */
/* Programa:Programa final | */
/* Año:2022 | */
/**********************************************************************/
// Conexiones puente h
//motor 1_izquierdo
int IN1=10; // enmascaro al pin 10 con el nombre de IN1
int IN2=9; // enmascaro al pin 9 con el nombre de IN2

//motor 2_derecho
int IN3=8; // enmascaro al pin 8 con el nombre de IN3
int IN4=7; // enmascaro al pin 7 con el nombre de IN4

int dato='o'; // creo la variable de lectura del bluetooth y la inicializo en 'o'

void setup()
{
Serial.begin(9600); // inicio el puerto serial para la comunicación con el bluetooth pinMode(IN1, OUTPUT); // configuro el pin donde conecte IN1 como salida pinMode(IN2, OUTPUT); // configuro el pin donde conecte IN2 como salida pinMode(IN3, OUTPUT); // configuro el pin donde conecte IN3 como salida pinMode(IN4, OUTPUT); // configuro el pin donde conecte IN4 como salida
}

void loop()

dato=Serial.read(); // leo el bluetooth y cargo el dato en la variable dato

if (dato== 'a') // si recibo una 'a' voy hacia adelante
{
//giro motor 1 sentido anti horario
digitalWrite(IN1,LOW); //envió 0V al pin donde conecte IN1 digitalWrite(IN2,HIGH); //envió 5V al pin donde conecte IN2 //giro motor 2 sentido horario
digitalWrite(IN3,HIGH); //envió 5V al pin donde conecte IN3 digitalWrite(IN4,LOW); //envió 0V al pin donde conecte IN4 delay(100);// demora de 10milisegundos
}
if (dato== 'b') // si recibo una 'b' voy hacia atras
{

//giro motor 1 sentido horario
digitalWrite(IN1,HIGH); //envió 5V al pin donde conecte IN1 digitalWrite(IN2,LOW); //envió 0V al pin donde conecte IN2 //giro motor 2 sentido antihorario
digitalWrite(IN3,LOW); //envió 0V al pin donde conecte IN3 digitalWrite(IN4,HIGH); //envió 5V al pin donde conecte IN4
}
if (dato== 'c') // si recibo una 'c' voy a la derecha con ambas ruedas
{
//giro motor 1 sentido anti horario
digitalWrite(IN1,LOW); //envió 0V al pin donde conecte IN1 digitalWrite(IN2,HIGH); //envió 5V al pin donde conecte IN2 //giro motor 2 sentido antihorario
digitalWrite(IN3,LOW); //envió 0V al pin donde conecte IN3

# Manual de Robot_Futbol con Arduino

digitalWrite(IN4,HIGH); //envió 5V al pin donde conecte IN4 delay(100);// demora de 10milisegundos
//motor 1 DETENIDO
digitalWrite(IN1,LOW); //envió 0V al pin donde conecte IN1 digitalWrite(IN2,LOW); //envió 0V al pin donde conecte IN2 //motor 2 DETENIDO
digitalWrite(IN3,LOW); //envió 0V al pin donde conecte IN3 digitalWrite(IN4,LOW); //envío 0V al pin donde conecte IN4
}
if (dato== 'd') // si recibo una 'd' voy a la izquierda con ambas ruedas
{
//giro motor 1 sentido horario
digitalWrite(IN1,HIGH); //envió 5V al pin donde conecte IN1 digitalWrite(IN2,LOW); //envió 0V al pin donde conecte IN2 //giro motor 2 sentido horario
digitalWrite(IN3,HIGH); //envió 5V al pin donde conecte IN3 digitalWrite(IN4,LOW); //envió 0V al pin donde conecte IN4 delay(100);// demora de 10milisegundos
//motor 1 DETENIDO
digitalWrite(IN1,LOW); //envió 0V al pin donde conecte IN1 digitalWrite(IN2,LOW); //envió 0V al pin donde conecte IN2 //motor 2 DETENIDO
digitalWrite(IN3,LOW); //envió 0V al pin donde conecte IN3 digitalWrite(IN4,LOW); //envío 0V al pin donde conecte IN4 delay(100);// demora de 10milisegundos
}
if (dato== 'e') // si recibo una 'e' me detengo
{
//motor 1 DETENIDO
digitalWrite(IN1,LOW); //envió 0V al pin donde conecte IN1 digitalWrite(IN2,LOW); //envió 0V al pin donde conecte IN2 //motor 2 DETENIDO
digitalWrite(IN3,LOW); //envió 0V al pin donde conecte IN3 digitalWrite(IN4,LOW); //envío 0V al pin donde conecte IN4
}
if (dato== 'f') // si recibo una 'c' voy a la derecha con una rueda
{
//giro motor 1 sentido anti horario
digitalWrite(IN1,LOW); //envió 0V al pin donde conecte IN1 digitalWrite(IN2,HIGH); //envió 5V al pin donde conecte IN2 delay(100);// demora de 10milisegundos
//motor 1 DETENIDO
digitalWrite(IN1,LOW); //envió 0V al pin donde conecte IN1 digitalWrite(IN2,LOW); //envió 0V al pin donde conecte IN2 delay(100);// demora de 10milisegundos
}
if (dato== 'g') // si recibo una 'd' voy a la izquierda con una rueda
{
//giro motor 2 sentido horario
digitalWrite(IN3,HIGH); //envió 5V al pin donde conecte IN3 digitalWrite(IN4,LOW); //envió 0V al pin donde conecte IN4 delay(100);//demora de 10milisegundos
//motor 2 DETENIDO
digitalWrite(IN3,LOW); //envió 0V al pin donde conecte IN3 digitalWrite(IN4,LOW); //envío 0V al pin donde conecte IN4 delay(100);// demora de 10milisegundos
}
}
}

# Manual de Robot_Futbol con Arduino

Se aclara que se espera que el lector modifique el programa para hacerlo compatible con la app que use y de esta manera darle mas rango de maniobrabilidad.

# Manual de Robot_Futbol con Arduino

# Diagrama de conexión final

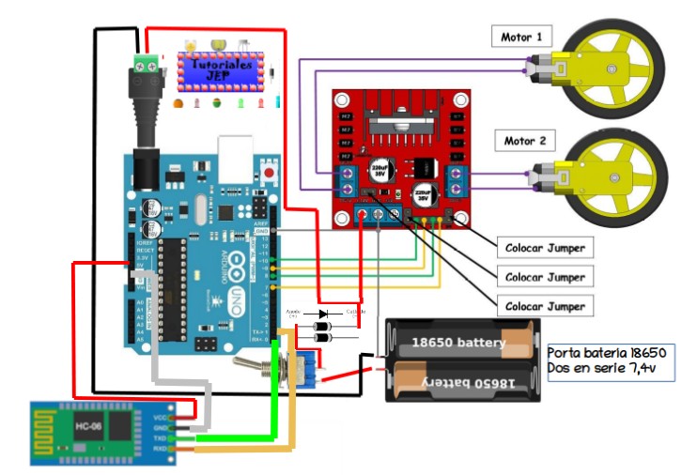
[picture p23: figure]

Ahora solo queda:
- Calibrar el programa en un cancha (de dimensiones según el reglamento) y con una pelota que cumpla con el reglamento. Teniendo en cuenta la APP que utilicen.
- Distribución del peso en el chasis para obtener la mayor tracción.
- Adecuarse a las normas de la categoría en la que participe.

Podrán descargar los archivos referentes al chasis del Robot en el canal de youtube TUTORIALES JEP. También se encontraran los archivos STL para imprimir con la impresora 3d.

# Robot_futbol_01: https://youtu.be/j2guSepUVq8

# Manual de Robot_Futbol con Arduino

# Imagen ilustrativa de la cancha:

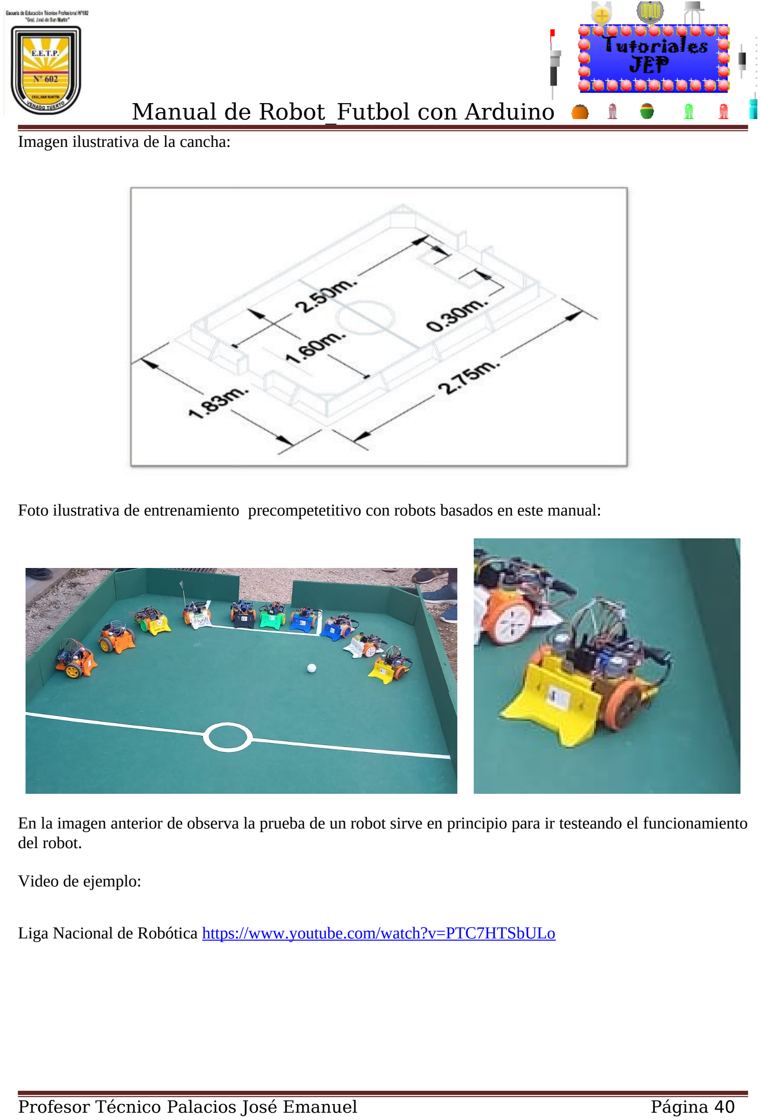
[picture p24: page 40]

# Foto ilustrativa de entrenamiento precompetetitivo con robots basados en este manual:

En la imagen anterior de observa la prueba de un robot sirve en principio para ir testeando el funcionamiento del robot.

# Video de ejemplo:

# Liga Nacional de Robótica https://www.youtube.com/watch?v=PTC7HTSbULo

# Manual de Robot_Futbol con Arduino

# Bibliografía:

# https://www.arduino.cc/en/main/software https://www.pololu.com/category/22/motors-and-gearboxes http://www.superrobotica.com/S320103.htm https://youtu.be/DdqFkJAV6l4 Robot_futbol_01: https://youtu.be/j2guSepUVq8

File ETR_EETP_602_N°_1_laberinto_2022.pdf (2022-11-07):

# Manual de robot laberinto con arduino


# Autor: Profesor Palacios José Emanuel

# Año: 2022

# Institución: Escuela de Educación Técnico Profesional Nº 602 "Gral San Martín" www.eetp602.edu.ar

# Manual de Robot_Laberinto con Arduino

# Contenido

Profesor Técnico Palacios José Emanuel | Página 2

# Manual de Robot_Laberinto con Arduino

Introducción: Robotlaberinto.

En este manual desarrollaremos un robotlaberinto funcional básico, que se espera sufra modificaciones por quien lee este manual. Existen diferentes tipos de laberintos pero si esta es tu primera vez programando un robot que resuelve laberintos lo mejor será empezar por algo “sencillo”. Nuestro laberinto tendrá su entrada y salida en el perímetro y no contendrá islas ni lazos cerrados. Puede haber divergencia de caminos y callejones sin salida. El siguiente ejemplo de laberintos podría servir. Nuestro robot debe ser capaz de resolverlo.

Materiales.

- 1x Arduino uno


- 1x Chasis que cumpla con las normas de la categoría (se proporcionaran planos de ejemplo).
- 2x motoreductor arduino
- Rueda para motoreductor arduino ( se proporciona plano para su diseño 3d).
- shiel doble puente h l298n.
- Porta baterías 18650 x2.
- Baterías recargables tipo 18650 3.7v 5000 Mah
- Plug de alimentación DC 2.1mm
- 30 tornillos cabeza tanque de 1/8 de 10mm con tuerca.
- 2 tornillos cabeza tanque de 1/8 de 30mm con tuerca (para la pala).
- 2 tornillo m2 X 15mm(diametro2mm) para sujetar ruedas.
- 20 conector dupont macho hembra 10cm
- 20 conector dupont macho macho10cm
- Cable 1mm rojo y negro, 50cm.
- Tecla on/0ff.
- 3 sensor ultrasonico hc-sr04
- 4 Diodo rectificador 1n4007
- Cinta aisladora o termocontraible (de 3 a 1mm).
- Estaño .
- Piezas del diseño de chasis (archivos stl para descargar https://youtu.be/j2guSepUVq8 )

# Manual de Robot_Laberinto con Arduino

# Interruptor on/off y alimentación

Es conveniente agregar un interruptor para la alimentación del circuito, en serie a un diodo rectificador 1N4007 (para proteger el circuito en caso de conectar las baterías con la polaridad incorrecta), de acuerdo al consumo es la cantidad de diodos 1N4007 que conectaremos ya que cada diodo soporta 1A, en este caso conectaremos 2 diodos en paralelo para que soporten 2A, de necesitar que soporte mas amperaje incrementar la cantidad de diodos o colocar uno que soporte dicho amperaje.


# Manual de Robot_Laberinto con Arduino

# Sensor ultrasonico hc-sr04

El Sensor de Distancia Ultrasónico (https://translate.googleusercontent.com/translate_c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) HC-SR04 es una solución popular y de bajo costo para la función de medición de distancia sin contacto. Es capaz de medir distancias de 2 cm a 400 cm con una precisión de aproximadamente 3 mm. Este módulo incluye transmisor ultrasónico, receptor ultrasónico y su circuito de control.

El módulo HC-SR04 tiene 4 pines:

- VCC - 5V, + ive de la fuente de alimentación
- TRIG - Pin del gatillo
- ECHO - Pin Echo
- GND - - de la fuente de alimentación

Los pines TRIG y ECHO se pueden usar para conectar este módulo con una unidad de microcontrolador. Estos son los pines de salida de entrada TTL (0 - 5V).

# Módulo ultrasónico HC-SR04 funcionando


- Proporcione la señal TRIGGER, al menos 10 μS de pulso de nivel alto (5V).
- El módulo transmitirá automáticamente ocho ráfagas ultrasónicas de 40 kHz.
- Si hay un obstáculo en frente del módulo, reflejará la explosión ultrasónica.
- Si la señal está de regreso, la salida ECHO del sensor estará en estado ALTO (5 V) durante un tiempo de envío y recepción de la explosión ultrasónica. El ancho del pulso varía de aproximadamente 150μS a 25mS y, si no se detecta ningún obstáculo, el ancho del pulso del eco será de aproximadamente 38 ms.

# Manual de Robot_Laberinto con Arduino


Empezamos insertando el sensor ultrasónico en un protoboard y con cables hacemos las siguientes

conexiones:

# – Trigger del sensor al pin 2 del arduino – Echo del sensor al pin 3 del arduino

Todas las conexiones se realizan con el Arduino Apagado (desconectado de la PC o de cualquier fuente

## externa):

Ahora abrimos el entorno de programación de Arduino, en Herramientas ->Tarjeta, y seleccionamos el modelo de placa Arduino que estemos utilizando. Nosotros seleccionaremos Arduino Uno.

# Manual de Robot_Laberinto con Arduino


Una vez configurado el IDE, empezamos a programar nuestro sketch, explicaremos paso a paso el código

## para sea más comprensible:

Primero configuramos los pines y la comunicación serial a 9800 baudios.

const int Trigger = | 2; | // enmascaro al pin 2 con el nombre de Trigger del sensor
const int Echo = | 3; | // enmascaro al pin 3 con el nombre de Echo del sensor

void setup() {

Serial.begin(9600);//iniciailzamos la comunicación

pinMode(Trigger, OUTPUT); //pin como salida

pinMode(Echo, INPUT); //pin como entrada

digitalWrite(Trigger, LOW);//Inicializamos el pin con 0
}

Ahora en el bucle void loop() empezamos enviando un pulso de 10us al Trigger del sensor.

digitalWrite(Trigger, HIGH); | // ponemos el pin trigger en 5v
delayMicroseconds(10); | //Esperamos 10us
digitalWrite(Trigger, LOW); | // ponemos el pin trigger en 0v

//con esto Enviamos un pulso de 10us

Seguidamente recibimos el pulso de respuesta del sensor por el pin Echo, para medir el pulso usamos la

# función pulseIn(pin, value)

# Manual de Robot_Laberinto con Arduino

## t=pulseIn(Echo, HIGH); //obtenemos el ancho del pulso

La variable t, tiene el tiempo que dura en llegar el eco del ultrasonido, el siguiente paso es calcular la distancia entre el sensor ultrasónico y el objeto.

## Partimos de la siguiente formula:

Donde Velocidad es la velocidad del sonido 340m/s, pero usaremos las unidades en cm/us pues trabajaremos en centímetros y microsegundos, tiempo es el tiempo que demora en llegar el ultrasonido al objeto y

regresar al sensor, y la distancia recorrida es dos veces la distancia hacia el objeto, reemplazando en la

## formula tenemos:

Finalmente enviamos serialmente el valor de la distancia y terminamos poniendo una pausa de 100ms, que

## es superior a los 60ms recomendado por los datos técnicos del sensor

# Manual de Robot_Laberinto con Arduino

A continuación se muestra el código completo del programa para testear un (1) sensor ultrasonico.

## Prueba de un (1) sensor ultrasonico HC-SR04

/**********************************************************************/
/* Autor: Palacios José Emanuel docente de la EETPN°602 | */
/* Programa:Prueba de un(1) sensor ultrasonico HC-SR04 | */
/* Año:2022 | */
/**********************************************************************/
const int Trigger = | 2; | // enmascaro al pin 2 con el nombre de Trigger del sensor
const int Echo = | 3; | // enmascaro al pin 3 con el nombre de Echo del sensor

void setup() {

Serial.begin(9600);//iniciailzamos la comunicación

pinMode(Trigger, OUTPUT); //pin como salida

pinMode(Echo, INPUT); //pin como entrada

digitalWrite(Trigger, LOW);//Inicializamos el pin con 0
}

void loop()
{
// VARIABLES PARA USAR CON EL SENSOR ULTRASONICO_1*********************

long t; //tiempo que demora en llegar el eco

long d; //distancia en centimetros

// ENVIO PULSO PARA EL SENSOR ULTRASONICO _ | 1
digitalWrite(Trigger, HIGH); | // ponemos el pin trigger en 5v
delayMicroseconds(10); | //Esperamos 10us
digitalWrite(Trigger, LOW); | // ponemos el pin trigger en 0v

//con esto Enviamos un pulso de 10us PARA EL SENSOR ULTRASONICO_1

t=pulseIn(Echo, HIGH); //obtenemos el ancho del pulso

d=t/59;//calculamos la distancia en cm

Serial.print("Distancia: ");

Serial.print(d); | //Enviamos serialmente el valor de la distancia
Serial.print("cm");
Serial.println();
delay(100); | //Hacemos una pausa de 100ms
}

Conecte el Arduino Uno y cargue el programa.

Después de esto el Arduino y sensor ya deben estar trabajando, para poder visualizar los datos vaya a herramientas y habrá el monitor serial.

En el monitor serial le aparecerán los valores de la distancia que censa el HC-SR04, ponga un objeto al frente y varíe su distancia respecto al sensor y verifique que la distancia mostrada en el monitor serial sea la

correcta.

# Manual de Robot_Laberinto con Arduino

# Manual de Robot_Laberinto con Arduino

A continuación se muestra el código completo del programa para testear dos (2) sensores ultrasonicos.

## Prueba de dos (2) sensores ultrasonicos HC-SR04

/**********************************************************************/
/* Autor: Palacios José Emanuel docente de la EETPN°602 | */
/* Programa:Prueba de dos(2) sensores ultrasonicos HC-SR04 | */
/* Año:2022 | */
/**********************************************************************/
const int Trigger = | 2; | // enmascaro al pin 2 con el nombre de Trigger del sensor 1
const int Echo = | 3; | // enmascaro al pin 3 con el nombre de Echo del sensor 1
const int Trigger2 = | 4; | // enmascaro al pin 4 con el nombre de Trigger2 del sensor 2
const int Echo2 = | 5; | // enmascaro al pin 5 con el nombre de Echo2 del sensor 2

void setup() {

Serial.begin(9600);//iniciailzamos la comunicación

pinMode(Trigger, OUTPUT); //pin como salida

pinMode(Echo, INPUT); //pin como entrada

digitalWrite(Trigger, LOW);//Inicializamos el pin con 0

## pinMode(Trigger2, OUTPUT); //pin como salida

pinMode(Echo2, INPUT); //pin como entrada

digitalWrite(Trigger2, LOW);//Inicializamos el pin con 0
}

void loop()
{
// VARIABLES PARA USAR CON EL SENSOR ULTRASONICO_1*********************

long t; //tiempo que demora en llegar el eco

long d; //distancia en centimetros

// ENVIO PULSO PARA EL SENSOR ULTRASONICO _ | 1
digitalWrite(Trigger, HIGH); | // ponemos el pin trigger en 5v
delayMicroseconds(10); | //Esperamos 10us
digitalWrite(Trigger, LOW); | // ponemos el pin trigger en 0v

//con esto Enviamos un pulso de 10us PARA EL SENSOR ULTRASONICO_1

t=pulseIn(Echo, HIGH); //obtenemos el ancho del pulso

d=t/59;//calculamos la distancia en cm

Serial.print("Distancia: ");

Serial.print(d); | //Enviamos serialmente el valor de la distancia
Serial.print("cm");
Serial.println();
delay(100); | //Hacemos una pausa de 100ms

// VARIABLES PARA USAR CON EL SENSOR ULTRASONICO_2*********************

long t2; //tiempo que demora en llegar el eco

long d2; //distancia en centimetros

// ENVIO PULSO PARA EL SENSOR ULTRASONICO _ | 2
digitalWrite(Trigger2, HIGH); | // ponemos el pin trigger en 5v
delayMicroseconds(10); | //Esperamos 10us
digitalWrite(Trigger2, LOW); | // ponemos el pin trigger en 0v

//con esto Enviamos un pulso de 10us PARA EL SENSOR ULTRASONICO_2

t2=pulseIn(Echo2, HIGH); //obtenemos el ancho del pulso

d2=t2/59;//calculamos la distancia en cm

# Manual de Robot_Laberinto con Arduino

Serial.print("Distancia2: ");

Serial.print(d2); | //Enviamos serialmente el valor de la distancia 2
Serial.print("cm");
Serial.println();
delay(100); | //Hacemos una pausa de 100ms
}

# Manual de Robot_Laberinto con Arduino

# Control de Motores

Nos queda por probar el movimiento de los motores, estos funcionan con un voltaje de corriente directa, para controlar el giro y la velocidad se usará un driver de motores.

Primero soldaremos los cables a los motores.

Se deben soldar los cables de manera perpendicular al motor de modo que la longitud del motor sea lo más corta posible (ahora que se ha incluido el cable).


Una vez soldados los motores debemos conectarlos al driver.
Shiel doble puente h l298n.


# Manual de Robot_Laberinto con Arduino

Este módulo es el complemento ideal para proyectos de robótica y Router CNC. Permite controlar hasta 2

motores de corriente continua o un motor paso a paso bipolar. También permite controlar un motor paso a

paso unipolar configurado como bipolar de forma muy sencilla y eficaz.

### Características

- Voltaje de alimentación, mínimo de 5 V. Posee dos entradas, una de 5V para controlar la parte lógica y otra para alimentar las salidas al motor, que pueden ser de 5V o más.
- La tarjeta tiene la opción de habilitar un regulador LM7805 integrado en ella para alimentar la parte lógica con lo que se puede alimentar la tarjeta con 12V por ejemplo.
- Corriente máxima 2 Amperios.

## - Posee 6 entradas de control (ver tabla de control)

- Admite entradas de señal PWM para el control de velocidad.
- Dimensiones: 43 mm x 23,9 mm x 43 mm.
- Salidas: para 2 motores de DC o para un motor bipolar paso a paso.

# Manual de Robot_Laberinto con Arduino

# Funcionamiento del puente H

El voltaje de entrada puede ser desde 3v hasta 35v, aun lado de la entrada de voltaje contamos con el

GND

## La tercera es la salida lógica de 5v la cual se utiliza de la siguiente manera:

- Si el jumper se encuentra puesto se activará el regulador de tensión y tendremos una salida de 5V, que podremos usar para darle potencia a otro componente.
- Si quitamos el jumper desactivaremos el regulador, necesitaríamos alimentar el módulo, Tendríamos que ingresar 5v por la salida lógica para que el modulo funcione.
- ¡PRECAUCION! Si ingresamos 5v por la parte lógica con el jumper puesto podríamos causar daño

a la tarjeta.
- El regulador solo nos funciona si ingresamos un voltaje desde 5v hasta 12v, Si queremos ingresar un voltaje mayor tendríamos que quitar el jumper y alimentar el modulo con 5v con una fuente externa.

Las salidas de los motores 1 y 2 nos dan energía para mover los motores. Hay que tomar en cuenta las polaridades de los motores para que queden girando hacia adelante. En caso de que un motor este girando al lado contrario solo es necesario invertir los cables.

Los dos pines IN1 e IN2 sirven para controlar el sentido de giro en el motor 1, y los dos pines IN3 e IN4 el sentido de giro del motor 2.

# Manual de Robot_Laberinto con Arduino

## Funcionan de la siguiente manera:

Si IN1 le llegan 5v y al IN2 0v, el motor 1 gira en un sentido, y si IN1 le llegan 0v y a IN2 5v lo hace en el sentido contrario.

Sería lo mismo con los pines IN3 e IN4 para el motor 2.

Para controlar la velocidad a la que van a girar los motores tenemos que retirar los jumpers en ENA y ENB. Los tenemos que conectar a dos salidas PWM de nuestro Arduino con el cual enviaremos una señal con un valor entre 0 y 255 para que controle la velocidad de giro. Si no quitamos los jumpers, los motores estarán

## girando a la misma velocidad siempre( que es el caso que se explica en este tutorial)

La siguiente imagen muestra las conexiones a realizar, para los pines ENA y ENB se dejan con los jumpers pero si quieren controlar la velocidad podemos utilizar cualquier conexión PWM en el arduino quitando los

jumpers.

Conexiones


# Manual de Robot_Laberinto con Arduino

# Programación para controlar el puente h

A continuación tenemos un código de ejemplo para controlar los motores:

/**********************************************************************/
/* Autor: Palacios José Emanuel docente de la EETPN°602 | */
/* Programa:Prueba motores | */
/* Año:2022 | */
/**********************************************************************/

// Conexiones puente h
//motor 1
int IN1=10; // enmascaro al pin 10 con el nombre de IN1 int IN2=9; // enmascaro al pin 9 con el nombre de IN2

//motor 2
int IN3=8; // enmascaro al pin 8 con el nombre de IN3
int IN4=7; // enmascaro al pin 7 con el nombre de IN4

// **************************** Inicialización *************************************
void setup() {
pinMode(IN1, OUTPUT); // configuro el pin donde conecte IN1 como salida pinMode(IN2, OUTPUT); // configuro el pin donde conecte IN2 como salida pinMode(IN3, OUTPUT); // configuro el pin donde conecte IN3 como salida pinMode(IN4, OUTPUT); // configuro el pin donde conecte IN4 como salida
}

//***************************** programa principal *******************************
void loop() {

//giro motor 1 sentido horario
digitalWrite(IN1,HIGH); //envió 5V al pin donde conecte IN1 digitalWrite(IN2,LOW); //envió 0V al pin donde conecte IN2 delay(1000); // Temporiza un segundo (1s = 1000ms)

//giro motor 1 sentido anti horario
digitalWrite(IN1,LOW); //envió 0V al pin donde conecte IN1 digitalWrite(IN2,HIGH); //envió 5V al pin donde conecte IN2 delay(1000); // Temporiza un segundo (1s = 1000ms)

//motor 1 DETENIDO
digitalWrite(IN1,LOW); //envió 0V al pin donde conecte IN1 digitalWrite(IN2,LOW); //envió 0V al pin donde conecte IN2 delay(1000); // Temporiza un segundo (1s = 1000ms)

//giro motor 2 sentido horario
digitalWrite(IN3,HIGH); //envió 5V al pin donde conecte IN3 digitalWrite(IN4,LOW); //envió 0V al pin donde conecte IN4 delay(1000); // Temporiza un segundo (1s = 1000ms)

//giro motor 2 sentido antihorario
digitalWrite(IN3,LOW); //envió 0V al pin donde conecte IN3 digitalWrite(IN4,HIGH); //envió 5V al pin donde conecte IN4 delay(1000); // Temporiza un segundo (1s = 1000ms)

//motor 2 DETENIDO
digitalWrite(IN3,LOW); //envió 0V al pin donde conecte IN3

# Manual de Robot_Laberinto con Arduino

digitalWrite(IN4,LOW); //envío 0V al pin donde conecte IN4 delay(1000); // Temporiza un segundo (1s = 1000ms)
}

# Manual de Robot_Laberinto con Arduino

## Lógica de movimiento

La estructura que hemos elegido para nuestro robot nos permitirá realizar movimientos hacia Adelante, hacia Atrás, giros a la Derecha, ala Izquierda y sobre sí mismo.
Movimiento hacia delante: Se hacen girar los dos motores en la misma dirección (sentido horario), esto provoca un movimiento recto hacia delante de la estructura.

Movimiento hacia atrás: Se hacen girar los dos motores en la misma dirección (antihorario), esto provoca un movimiento recto hacia atrás de la estructura.


# Manual de Robot_Laberinto con Arduino


Movimiento hacia la derecha: Se hace girar el motor izquierdo hacia delante (horario)y el motor de la Derecha hacia atrás(antihorario). Esto provoca un movimiento de giro ala Derecha de la estructura.

Movimiento hacia la izquierda: Se hace girar el motor de la Izquierda hacia atrás (antihorario) y el motor de la Derecha hacia delante (horario), esto provoca un movimiento de giro a la Izquierda de la estructura.

# Manual de Robot_Laberinto con Arduino

## El código de Arduino quedaría de la siguiente manera:

/**********************************************************************/
/* Autor: Palacios José Emanuel docente de la EETPN°602 | */
/* Programa:movimiento de robot | */
/* Año:2022 | */
/**********************************************************************/
// Conexiones puente h
//motor 1_izquierdo
int IN1=10; // enmascaro al pin 10 con el nombre de IN1
int IN2=9; // enmascaro al pin 9 con el nombre de IN2

//motor 2_derecho
int IN3=8; // enmascaro al pin 8 con el nombre de IN3 int IN4=7; // enmascaro al pin 7 con el nombre de IN4

void setup()
{

pinMode(IN1, OUTPUT); // configuro el pin donde conecte IN1 como salida pinMode(IN2, OUTPUT); // configuro el pin donde conecte IN2 como salida pinMode(IN3, OUTPUT); // configuro el pin donde conecte IN3 como salida pinMode(IN4, OUTPUT); // configuro el pin donde conecte IN4 como salida
}

void loop()
{
// voy hacia adelante por un segundo

//giro motor 1 sentido anti horario
digitalWrite(IN1,LOW); //envió 0V al pin donde conecte IN1 digitalWrite(IN2,HIGH); //envió 5V al pin donde conecte IN2 //giro motor 2 sentido horario
digitalWrite(IN3,HIGH); //envió 5V al pin donde conecte IN3 digitalWrite(IN4,LOW); //envió 0V al pin donde conecte IN4 delay(1000);// demora de un segundo

//voy hacia atrás por un segundo

//giro motor 1 sentido horario
digitalWrite(IN1,HIGH); //envió 5V al pin donde conecte IN1 digitalWrite(IN2,LOW); //envió 0V al pin donde conecte IN2 //giro motor 2 sentido antihorario
digitalWrite(IN3,LOW); //envió 0V al pin donde conecte IN3 digitalWrite(IN4,HIGH); //envió 5V al pin donde conecte IN4 delay(1000);// demora de un segundo

//voy a la derecha con ambas ruedas por un segundo

//giro motor 1 sentido anti horario
digitalWrite(IN1,LOW); //envió 0V al pin donde conecte IN1 digitalWrite(IN2,HIGH); //envió 5V al pin donde conecte IN2 //giro motor 2 sentido antihorario
digitalWrite(IN3,LOW); //envió 0V al pin donde conecte IN3 digitalWrite(IN4,HIGH); //envió 5V al pin donde conecte IN4 delay(1000);// demora de un segundo

# Manual de Robot_Laberinto con Arduino

// voy a la izquierda con ambas ruedas por un segundo

//giro motor 1 sentido horario
digitalWrite(IN1,HIGH); //envió 5V al pin donde conecte IN1 digitalWrite(IN2,LOW); //envió 0V al pin donde conecte IN2 //giro motor 2 sentido horario
digitalWrite(IN3,HIGH); //envió 5V al pin donde conecte IN3 digitalWrite(IN4,LOW); //envió 0V al pin donde conecte IN4 delay(1000);// demora de un segundo

// me detengo por un segundo

//motor 1 DETENIDO
digitalWrite(IN1,LOW); //envió 0V al pin donde conecte IN1 digitalWrite(IN2,LOW); //envió 0V al pin donde conecte IN2 //motor 2 DETENIDO
digitalWrite(IN3,LOW); //envió 0V al pin donde conecte IN3 digitalWrite(IN4,LOW); //envío 0V al pin donde conecte IN4 delay(1000);// demora de un segundo

// voy a la derecha con una rueda por un segundo

//giro motor 1 sentido anti horario
digitalWrite(IN1,LOW); //envió 0V al pin donde conecte IN1 digitalWrite(IN2,HIGH); //envió 5V al pin donde conecte IN2 delay(100);// demora de 10milisegundos
//motor 1 DETENIDO
digitalWrite(IN1,LOW); //envió 0V al pin donde conecte IN1 digitalWrite(IN2,LOW); //envió 0V al pin donde conecte IN2 delay(1000);// demora de un segundo

//voy a la izquierda con una rueda por un segundo

//giro motor 2 sentido horario
digitalWrite(IN3,HIGH); //envió 5V al pin donde conecte IN3 digitalWrite(IN4,LOW); //envió 0V al pin donde conecte IN4 delay(100);//demora de 10milisegundos
//motor 2 DETENIDO
digitalWrite(IN3,LOW); //envió 0V al pin donde conecte IN3 digitalWrite(IN4,LOW); //envío 0V al pin donde conecte IN4 delay(1000);// demora de un segundo

}

Con este programa comprobamos los movimientos del robot. Se espera que el lector corrija cualquier error de notar alguno.

# Manual de Robot_Laberinto con Arduino

Montaje de los componentes.

Cuando ya se han probado todos los componentes por separado lo siguiente es montar todo el circuito electrónico, sensores, motores y control en el chasis. Recomendamos el tornillos.

1) Partiremos por la base impresa en 3d

# Manual de Robot_Laberinto con Arduino

## Rueda loca


2) Montamos la rueda loca
3) Montamos el soporte para los porta baterías.

## y orificio para tornillos

# Manual de Robot_Laberinto con Arduino

4) Aquí el detalle de los tornillos de sujeción.

5) detalle de los motores sin los porta motores.

# Manual de Robot_Laberinto con Arduino

## motor


6) Detalle de los motores con los porta motores.
7) Colocamos las rudas (llanta y cubierta).

## portamotor

## tornillos

# Manual de Robot_Laberinto con Arduino

8) Posicionamos el modulo Bluetooth
9) Detalle del montaje de la pala.

## tornillos

## pala

# Manual de Robot_Laberinto con Arduino


10) Detalle del montaje del Arduino uno.
11) Detalle del montaje del puenteh.

## tornillo

## tornillo

# Manual de Robot_Laberinto con Arduino


12) Detalle del montaje de sensores ultrasonicos opcionales para robot_laberinto.
13) Detalle de habitáculo para las baterías.

## Tornillos

# Manual de Robot_Laberinto con Arduino


14) Detalle del montaje del portabaterias.
15) Detalle del montaje de la tapa del porta baterías .

## tornillos

# Manual de Robot_Laberinto con Arduino


16)Detalle conexión de porta tecla on/off.

17) detalle con el porta tecla atornillado.

## Orificio para tornillo de soporte tecla

## Soporte tecla

# Manual de Robot_Laberinto con Arduino


18)Detalle distintos soportes para interruptores de distintos tipos:

19)Detalle de soporte para sensores TCR500 y sensor ultrasonico para robot sumo.

## Soporte sensores

## TCR500

# Manual de Robot_Laberinto con Arduino

20)Detalle pala para sumo.

21)Detalle de rueda la cual consta de dos partes la llanta a imprimirse en PLA y la cubierta a imprimirse en material flexible.

## Material flexible Para la cubierta

## Material duro Pla para la llanta

# Manual de Robot_Laberinto con Arduino


22) Detalle soporte para modulo Bluetooth y modulo RF receptor.
23) Detalle del robot armado.

Nota: para el robot laberinto no es necesario instalar la pala y el modulo Bluetooth o el modulo FR.

# Manual de Robot_Laberinto con Arduino

24) Detalle orificio para arduino nano,

# Manual de Robot_Laberinto con Arduino


25) Detalle orificio para arduino nano con expansor.

# Manual de Robot_Laberinto con Arduino


26) Detalle orificio para arduino mega,

# Manual de Robot_Laberinto con Arduino

27) Detalle orificio para micromotorreductor.

27)Micromotorreductor y soporte motorreductor.

# Manual de Robot_Laberinto con Arduino

# Lógica para la programación de la aplicación final

Para unir todas las funciones se hace un programa que resuelve un laberinto debemos primero entender como solucionarlo.

El siguiente ejemplo de laberintos podría servir. Nuestro robot debe ser capaz de resolverlo.


Para resolver este tipo de laberintos será suficiente con implementar un algoritmo para robot seguidor

de paredes. Este algoritmo consiste en mantener el seguimiento de una pared priorizando un lado,

derecha o izquierda, y mantener el seguimiento hasta encontrar la salida del laberinto. Una calle sin salida

hay que tomarla como una pared que no acaba.

La mayoría de laberintos recreativos que hay en grandes jardines y parques son laberintos de este tipo

precisamente por seguridad, para que puedan ser resueltos sencillamente siguiendo una pared.

Para poder entender mejor cómo funciona un seguidor de pared aquí podes ver cómo debería resolver el

robot uno de los laberintos que mostraba arriba dando prioridad a la derecha o a la izquierda. El algoritmo

no es lo complicado, viendo el diagrama se puede entender el funcionamiento, lo interesante es

averiguar la manera de implementarlo en nuestro robot, en este caso el “robotlaberinto”.

# Manual de Robot_Laberinto con Arduino


En la imagen anterior se observa el laberinto que usamos de ejemplo resuelto con la lógica de ir pegado a

la pared izquierda (imagen izquierda) y con la lógica de ir pegado a la pared derecha ( imagen derecha)

¿A que ahora se entiende mejor? Te sorprenderías de la cantidad de laberintos que se pueden resolver

así.

Cuando hagas las pruebas no hace falta que utilices un laberinto de pruebas tan grande como el del ejemplo.

Si conseguís que el robot resuelva un laberinto pequeño, podrá resolver uno grande. Realmente no importa el tamaño del laberinto mientras sea de este tipo.

Una vez conocida la solución que le vamos a dar al problema, llega el momento de diseñar la

implementación, tanto a nivel de electrónica , mecánica, utilización de sensores como de programación.

# Manual de Robot_Laberinto con Arduino

## El diagrama de flujo sería el siguiente:

Se espera que el lector complete la lógica.

# Manual de Robot_Laberinto con Arduino

## El código de Arduino quedaría de la siguiente manera:

/**********************************************************************/
/* Autor: Palacios José Emanuel docente de la EETPN°602 | */
/* Programa:Programa final | */
/* Año:2022 | */
/**********************************************************************/
// Conexiones puente h
//motor 1_izquierdo
int IN1=10; // enmascaro al pin 10 con el nombre de IN1
int IN2=9; // enmascaro al pin 9 con el nombre de IN2

//motor 2_derecho
int IN3=8; // enmascaro al pin 8 con el nombre de IN3 int IN4=7; // enmascaro al pin 7 con el nombre de IN4

// Conexiones sensores utrasonicos
// sensor 1 derecha
const int Trigger = | 2; | // enmascaro al pin 2 con el nombre de Trigger del sensor 1
const int Echo = | 3; | // enmascaro al pin 3 con el nombre de Echo del sensor 1

// sensor 1 izquierda
const int Trigger2 = | 4; | // enmascaro al pin 4 con el nombre de Trigger2 del sensor 2
const int Echo2 = | 5; | // enmascaro al pin 5 con el nombre de Echo2 del sensor 2

// sensor 3 frente
const int Trigger3 = | 12; | // enmascaro al pin 4 con el nombre de Trigger2 del sensor 2
const int Echo3 = | 13; | // enmascaro al pin 5 con el nombre de Echo2 del sensor 2

void setup()
{
Serial.begin(9600); // inicio el puerto serial para la comunicación con el puerto serial de ser necesario // habilito pines puente h
pinMode(IN1, OUTPUT); // configuro el pin donde conecte IN1 como salida
pinMode(IN2, OUTPUT); // configuro el pin donde conecte IN2 como salida
pinMode(IN3, OUTPUT); // configuro el pin donde conecte IN3 como salida pinMode(IN4, OUTPUT); // configuro el pin donde conecte IN4 como salida // habilito pines sensores ultrasonicos

pinMode(Trigger, OUTPUT); //pin como salida

pinMode(Echo, INPUT); //pin como entrada

digitalWrite(Trigger, LOW);//Inicializamos el pin con 0

## pinMode(Trigger2, OUTPUT); //pin como salida

pinMode(Echo2, INPUT); //pin como entrada

digitalWrite(Trigger2, LOW);//Inicializamos el pin con 0

## pinMode(Trigger3, OUTPUT); //pin como salida

pinMode(Echo3, INPUT); //pin como entrada

digitalWrite(Trigger3, LOW);//Inicializamos el pin con 0

// demora de 5 segundos para darnos tiempo a soltar el robot

delay(5000); // corroborar el tiempo según reglamento

}

void loop()
{

# Manual de Robot_Laberinto con Arduino

lectura de sensores ultrasonicos
// VARIABLES PARA USAR CON EL SENSOR ULTRASONICO_1*********************

long t; //tiempo que demora en llegar el eco

long d_derecha; //distancia en centimetros

// ENVIO PULSO PARA EL SENSOR ULTRASONICO _ | 1
digitalWrite(Trigger, HIGH); | // ponemos el pin trigger en 5v
delayMicroseconds(10); | //Esperamos 10us
digitalWrite(Trigger, LOW); | // ponemos el pin trigger en 0v

//con esto Enviamos un pulso de 10us PARA EL SENSOR ULTRASONICO_1_derecha

t=pulseIn(Echo, HIGH); //obtenemos el ancho del pulso

d_derecha=t/59;//calculamos la distancia en cm

Serial.print("Distancia derecha: ");

Serial.print(d_derecha); | //Enviamos serialmente el valor de la distancia
Serial.print("cm");
Serial.println();
delay(100); | //Hacemos una pausa de 100ms

// VARIABLES PARA USAR CON EL SENSOR ULTRASONICO_2_izquierda*********************

long t2; //tiempo que demora en llegar el eco

long d2_izquierda; //distancia en centimetros

// ENVIO PULSO PARA EL SENSOR ULTRASONICO _ | 2
digitalWrite(Trigger2, HIGH); | // ponemos el pin trigger en 5v
delayMicroseconds(10); | //Esperamos 10us
digitalWrite(Trigger2, LOW); | // ponemos el pin trigger en 0v

//con esto Enviamos un pulso de 10us PARA EL SENSOR ULTRASONICO_2

t2=pulseIn(Echo2, HIGH); //obtenemos el ancho del pulso

d2_izquierda=t2/59;//calculamos la distancia en cm

Serial.print("Distancia2 izquierda: ");

Serial.print(d2_izquierda); | //Enviamos serialmente el valor de la distancia 2
Serial.print("cm");
Serial.println();
delay(100); | //Hacemos una pausa de 100ms

// VARIABLES PARA USAR CON EL SENSOR ULTRASONICO_3_frente*********************

long t3; //tiempo que demora en llegar el eco

long d3_frente; //distancia en centimetros

// ENVIO PULSO PARA EL SENSOR ULTRASONICO _ | 2
digitalWrite(Trigger3, HIGH); | // ponemos el pin trigger en 5v
delayMicroseconds(10); | //Esperamos 10us
digitalWrite(Trigger3, LOW); | // ponemos el pin trigger en 0v

//con esto Enviamos un pulso de 10us PARA EL SENSOR ULTRASONICO_3

t3=pulseIn(Echo3, HIGH); //obtenemos el ancho del pulso

d3_frente=t3/59;//calculamos la distancia en cm

Serial.print("Distancia frente: ");

Serial.print(d3_frente); | //Enviamos serialmente el valor de la distancia 3
Serial.print("cm");
Serial.println();
delay(100); | //Hacemos una pausa de 100ms

// con esto ya leimos las distancias frontal y a los costados

# Manual de Robot_Laberinto con Arduino

// ahora queda tomar las decisiones en función de esos datos

// d_derecha
// d2_izquierda

// d3_frente

### //************************** TOMA DE DECISIONES

************************************************************

// si la distancia derecha es menor a 10cm(hay pared) y la distancia izquierda es menor a 10cm ( hay pared) y la distancia en frente es mayor a 10cm( no hay pared cerca)
if((d_derecha<= 10)&&(d2_izquierda<= 10)&&(d3_frente>= 10)){
// entonces voy hacia adelante

// hacia adelante
//giro motor 1 sentido anti horario
digitalWrite(IN1,LOW); //envió 0V al pin donde conecte IN1 digitalWrite(IN2,HIGH); //envió 5V al pin donde conecte IN2 //giro motor 2 sentido horario
digitalWrite(IN3,HIGH); //envió 5V al pin donde conecte IN3 digitalWrite(IN4,LOW); //envió 0V al pin donde conecte IN4 delay(100);// demora de 10milisegundos
}

// si la distancia derecha es mayor a 10cm(no hay pared cerca) y la distancia izquierda es menor a 10cm ( hay pared) y la distancia en frente es menor a 10cm( hay pared )
if((d_derecha>= 10)&&(d2_izquierda<= 10)&&(d3_frente<= 10)){

//voy a la derecha con una rueda

}
// continuar la lógica

}

El deja al lector completar el programa en base a la lógica planteada.

# Manual de Robot_Laberinto con Arduino

# Diagrama de conexión final


# Manual de Robot_Laberinto con Arduino

Ahora solo queda:
- Calibrar el programa en un cancha (de dimensiones según el reglamento).
- Distribución del peso en el chasis para obtener la mayor tracción.
- Adecuarse a las normas de la categoría en la que participe.

Podrán descargar los archivos referentes al chasis del Robot en el canal de youtube TUTORIALES JEP. También se encontraran los archivos STL para imprimir con la impresora 3d.

## Robot_futbol_01: https://youtu.be/j2guSepUVq8

# Manual de Robot_Laberinto con Arduino

# Bibliografía:

## https://www.arduino.cc/en/main/software https://www.pololu.com/category/22/motors-and-gearboxes http://www.superrobotica.com/S320103.htm

## https://youtu.be/DdqFkJAV6l4

## Robot_futbol_01: https://youtu.be/j2guSepUVq8 https://juegosrobotica.es/retos/reto-mbot-robot-laberinto/

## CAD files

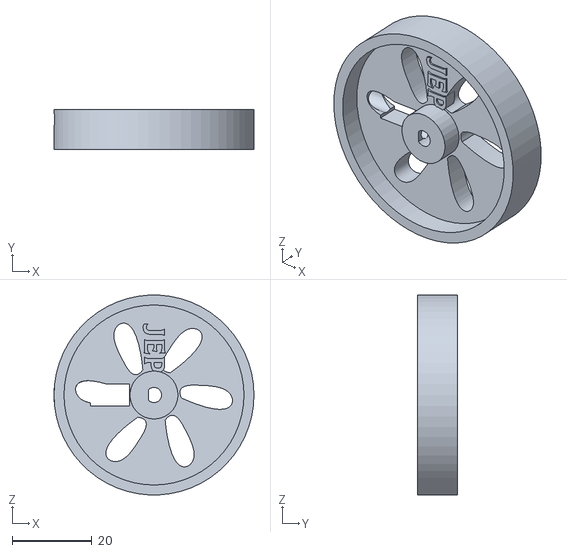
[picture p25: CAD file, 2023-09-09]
modelos 3d para imprimir/robot_futbool_02_llanta_micromotor_diametro_50_ancho_10mm_chaveta_y_tornillo.stl
50.0 x 10.0 x 49.9

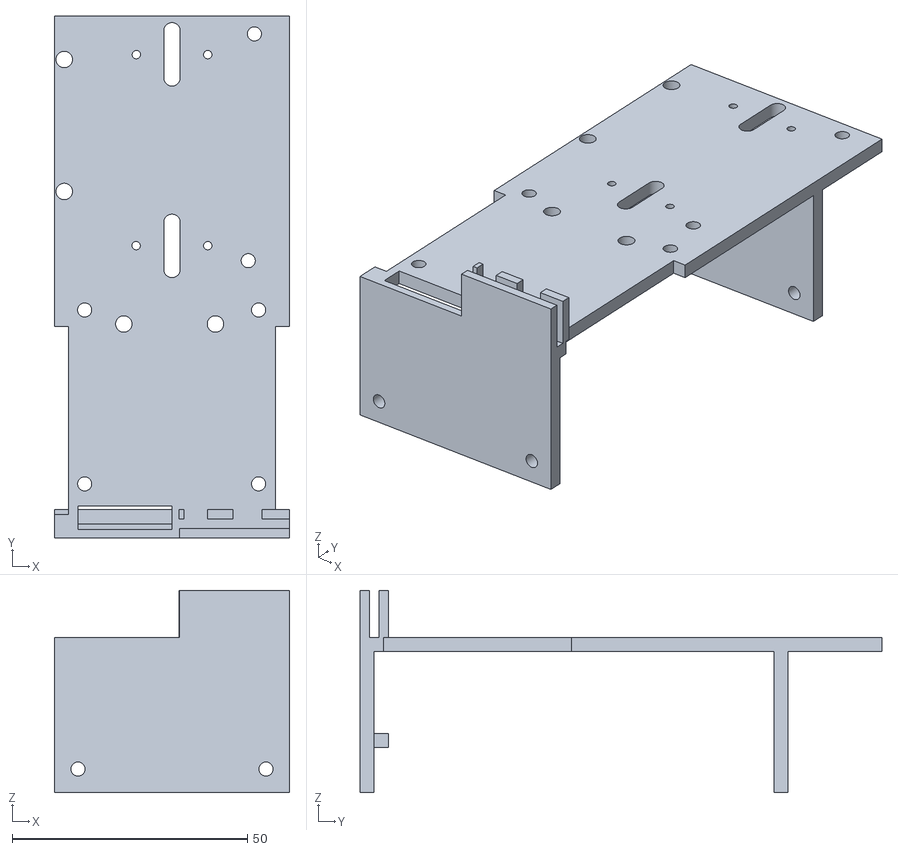
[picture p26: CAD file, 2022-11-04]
modelos 3d para imprimir/robot_futbool_02_portabaterias.stl
50.0 x 111.0 x 43.0

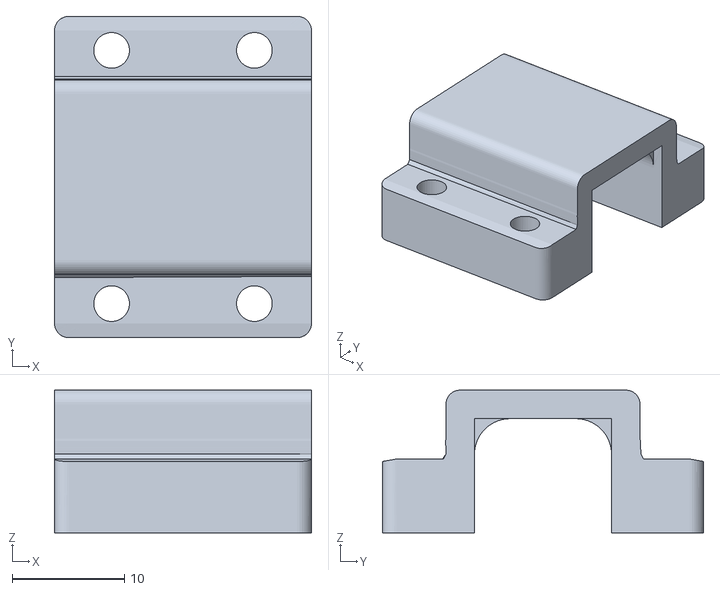
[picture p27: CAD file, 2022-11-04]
modelos 3d para imprimir/robot_futbool_02_soporte_micromotor.stl
22.9 x 28.6 x 12.7

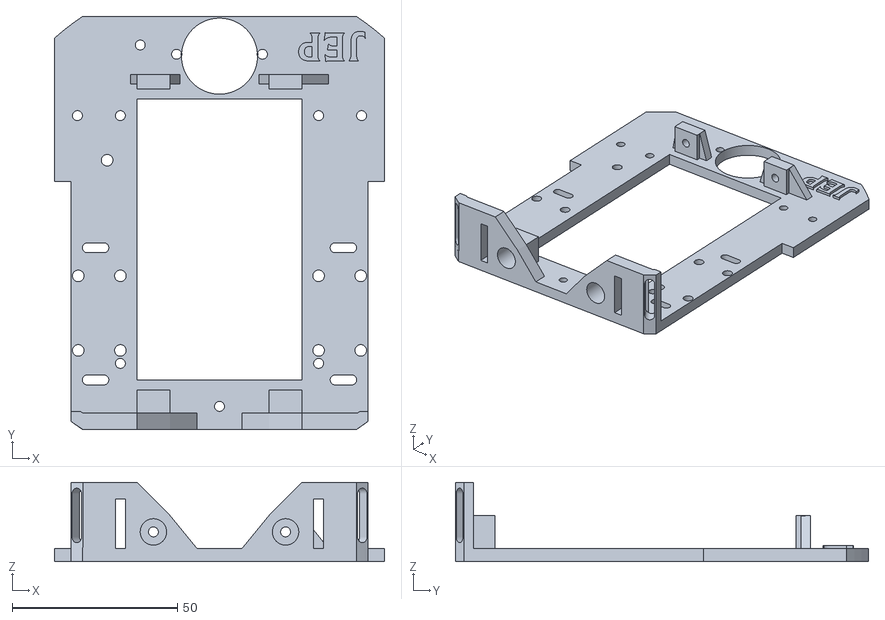
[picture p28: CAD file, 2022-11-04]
modelos 3d para imprimir/robot_futbool_02_chasis.stl
100.0 x 125.0 x 24.0

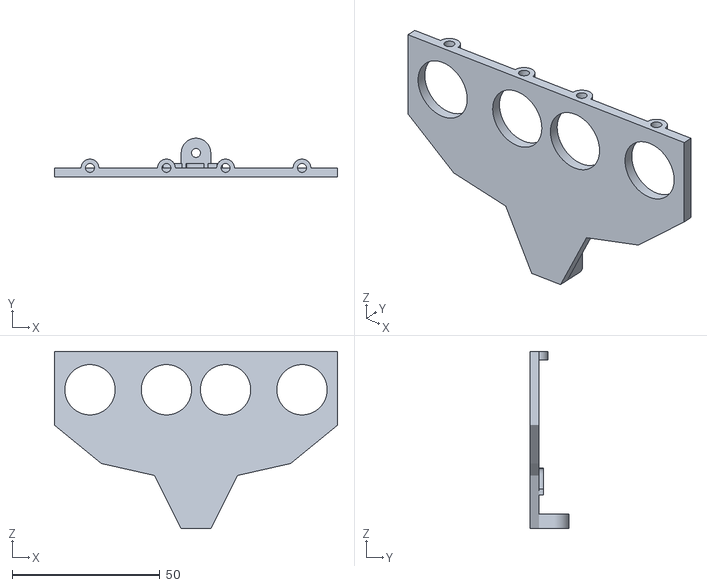
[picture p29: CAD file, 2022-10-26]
modelos 3d para imprimir/robot_futbool_02_soporte_ultrasonicox2.stl
95.7 x 13.1 x 60.0

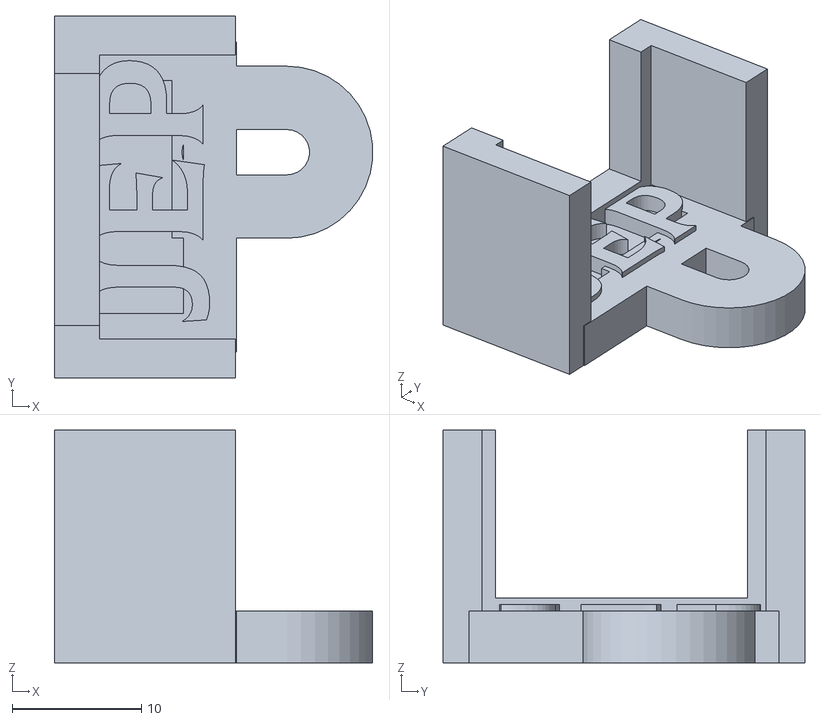
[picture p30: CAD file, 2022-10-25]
modelos 3d para imprimir/robot_futbool_02_soporte_interruptor_cuadrado.stl
24.6 x 28.0 x 18.0

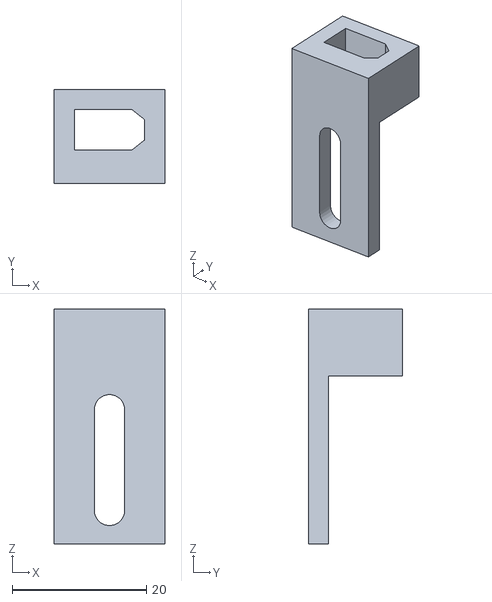
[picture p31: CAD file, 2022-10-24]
modelos 3d para imprimir/robot_futbool_02_soporte_tcr5000.stl
16.5 x 14.0 x 35.0

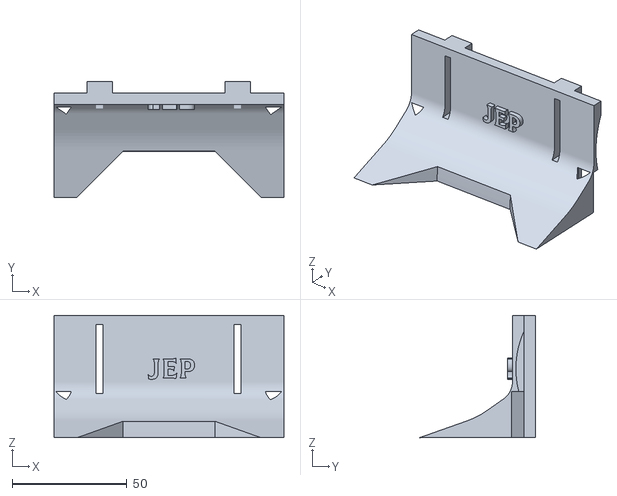
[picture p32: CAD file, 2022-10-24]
modelos 3d para imprimir/robot_futbool_02_pala_sumo.stl
100.0 x 50.4 x 53.2

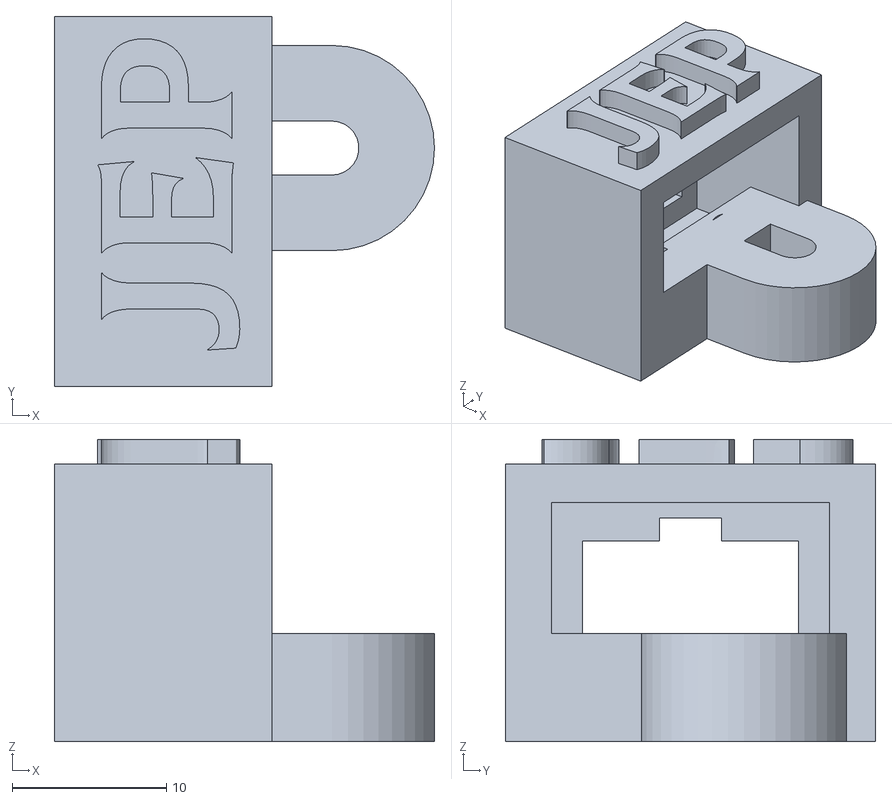
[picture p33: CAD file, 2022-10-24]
modelos 3d para imprimir/robot_futbool_02_soporte_interruptor.stl
24.6 x 24.0 x 19.6

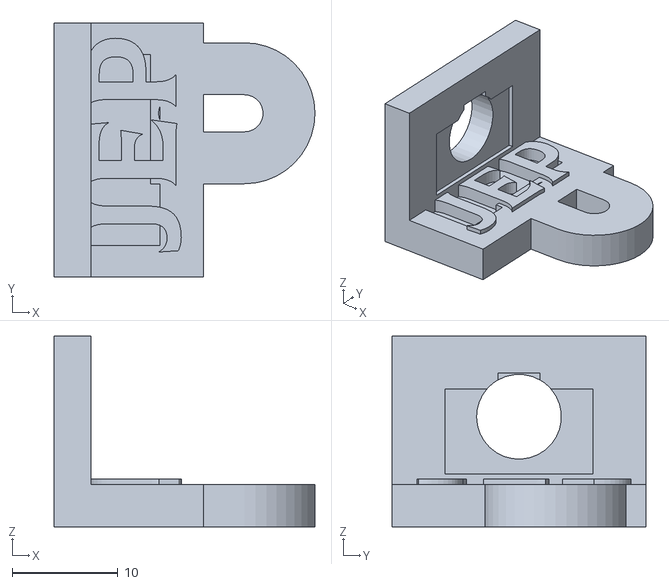
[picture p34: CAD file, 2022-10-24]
modelos 3d para imprimir/robot_futbool_02_soporte_interruptor_horizontal_redondo.stl
24.6 x 24.0 x 18.0

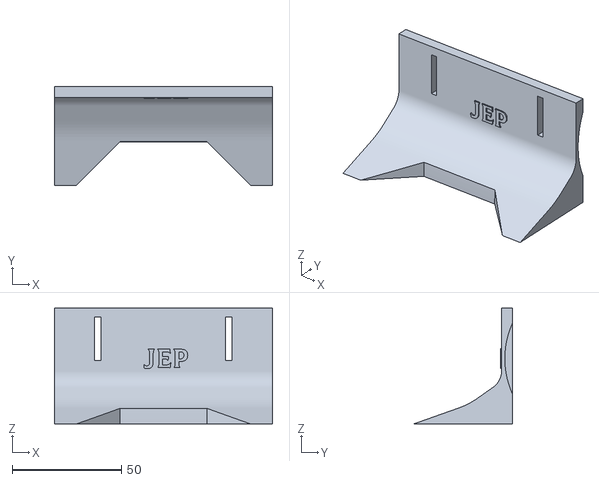
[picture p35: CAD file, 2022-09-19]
modelos 3d para imprimir/robot_futbool_02_pala.stl
100.0 x 45.4 x 53.2

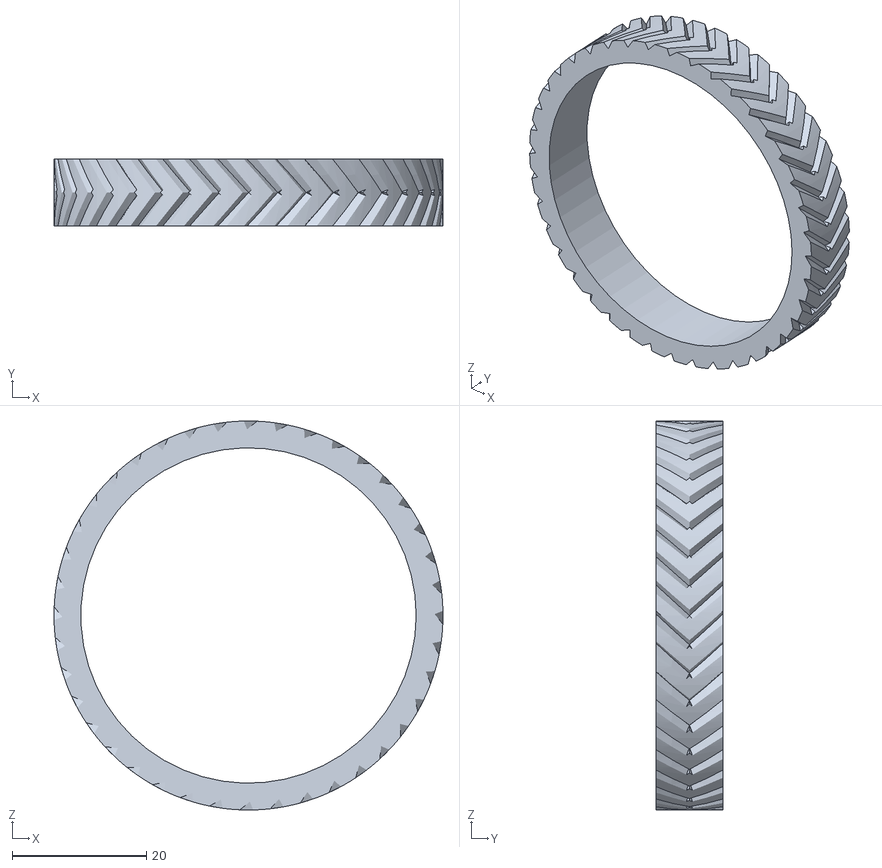
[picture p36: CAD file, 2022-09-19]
modelos 3d para imprimir/robot_futbool_02_llanta_motor_arduino-cubierta002.stl
58.0 x 10.0 x 58.0

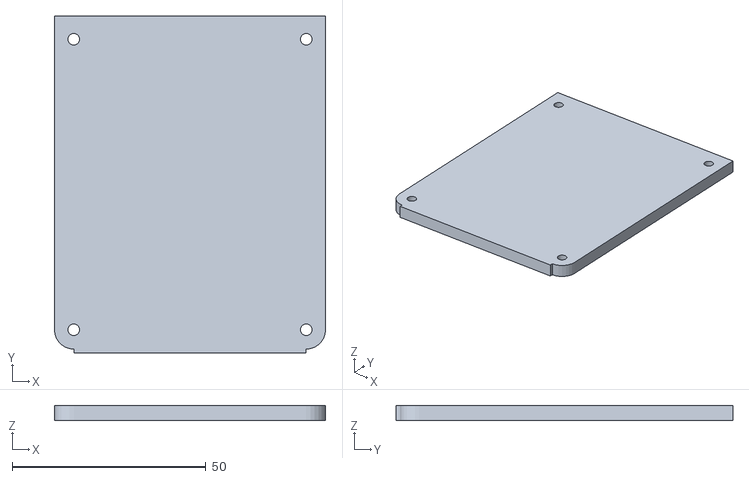
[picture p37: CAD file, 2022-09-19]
modelos 3d para imprimir/robot_futbool_02-tapa_baterias.stl
70.0 x 87.0 x 4.00

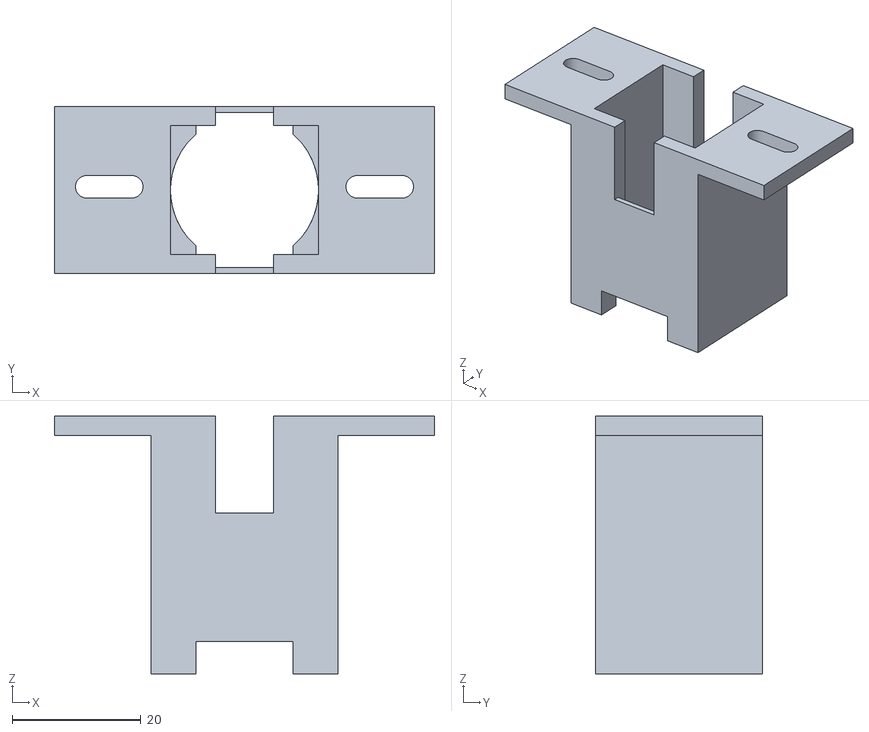
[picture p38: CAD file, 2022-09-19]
modelos 3d para imprimir/robot_futbool_02_soporte motor arduino-SOPORTE MOTOR ARDUINO VERTICAL.stl
59.0 x 26.0 x 40.0

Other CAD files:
modelos 3d para imprimir/robot_futbool_02_llanta_motor_arduino_diametro_50_ancho_10mm_chaveta_y_tornillo.stl
modelos 3d para imprimir/robot_futbool_02_rueda_loca_canica_mini.stl
modelos 3d para imprimir/robot_futbool_02_llanta_motor_arduino.stl
modelos 3d para imprimir/robot_futbool_02_soporte ultrasonico.stl
